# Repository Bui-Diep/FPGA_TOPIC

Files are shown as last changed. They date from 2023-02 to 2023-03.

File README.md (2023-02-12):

# FPGA_TOPIC
# Nghiên cứu xây dựng thiết bị kiểm tra bảng mạch chức năng của thiết thiết bị kiểm tra PKY-13 trên cơ sở FPGA.
## Research and build test equipment for functional circuit boards of PKY-13 test equipment on the basis of FPGA !!!
-----
## 3D and 2D images :
altium_3D
altium_2D
<br /><br /><br /><br /><br /><br />
<br /><br /><br />
<br /><br /><br /><br />

## Schematic : 
altium_sche

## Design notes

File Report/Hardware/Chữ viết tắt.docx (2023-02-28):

Chữ viết tắt:

Mạch giao tiếp | Khối truyền thông
- FPGA - USB - TTL - CMOS - AD - SDM - RAM - DC - JTAG - ROM - IC - VCC - GND - TXD - RXD - PCB - LED - OE - IC | - FPGA - UART - TX - RX - GND - TTL - COM - LSB - ASMD - FIFO - UCR - UCT - BRG - IC

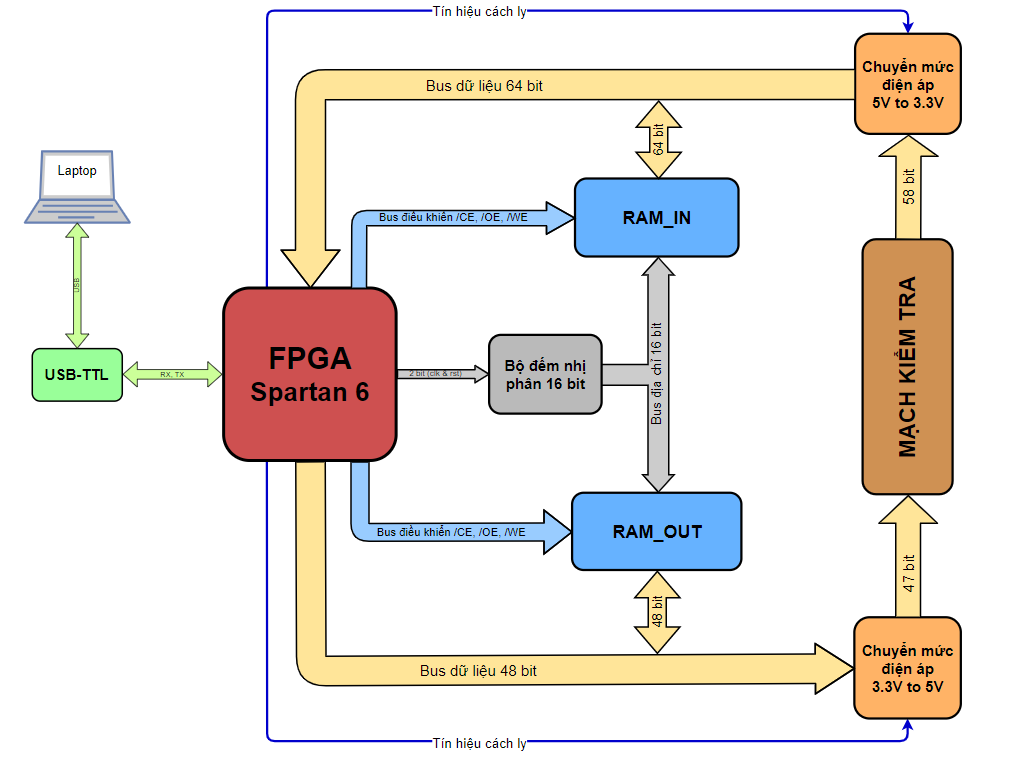
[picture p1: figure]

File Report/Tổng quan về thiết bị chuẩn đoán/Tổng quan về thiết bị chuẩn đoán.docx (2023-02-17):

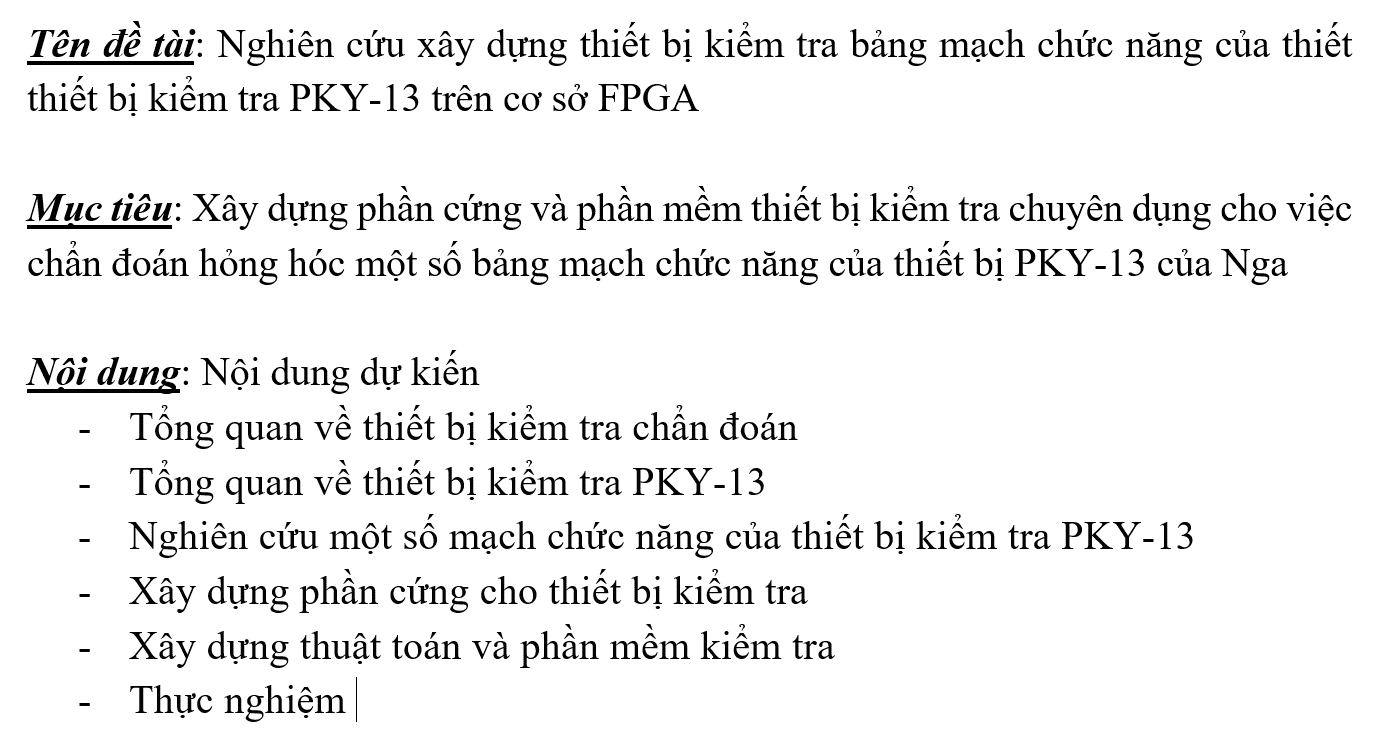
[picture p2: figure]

Báo cáo

Thiết bị kiểm tra chuẩn đoán là các thiết bị sử dụng để dự đoán tình hình hoạt động của thiết bị, khả năng cung cấp thông tin và đầu ra song song với các giá trị đúng. Chúng cũng có thể được sử dụng để kiểm tra chính xác của dữ liệu trong các ứng dụng.

Một số thiết bị kiểm tra chuẩn đoán thông dụng được sử dụng trong các ứng dụng khoa học cho phép các nhà nghiên cứu, kỹ thuật và các chuyên gia làm việc với các dữ liệu thực. Một số trong các thiết bị kiểm tra chuẩn đoán cho phép đầu ra song song để so sánh với các giá trị tham số, câu trả lời và hình ảnh.

Các thiết bị kiểm tra chuẩn đoán được sử dụng trong rất nhiều hãng sản xuất thiết bị, bao gồm cả các hãng lớn và nhỏ. Nhiều trong các thiết bị này được sử dụng trong các hệ thống quy trình và được thiết lập để theo dõi và giám sát các thông số của thiết bị.

Thiết bị kiểm tra chuẩn đoán hỏng hóc bảng mạch (PCB diagnostic tool) là dụng cụ phổ biến được sử dụng trong việc giám sát và kiểm soát các lỗi trên bảng mạch. Thiết bị này giúp bạn nhận ra và xác định các lỗi trên PCB (printed circuit board), từ những lỗi đơn giản như vi phạm hoặc gián đoạn vỡ dây đến những lỗi phức tạp hơn như hiện tượng ướt chân, áp suất và thất thoái pin. Thiết bị này không chỉ là hữu ích cho các nghiên cứu thực tế, nó còn giúp đảm bảo rằng PCB luôn làm việc chính xác và ổn định.

Thiết bị kiểm tra chuẩn đoán lỗi trên bảng mạch (debugging) là một công cụ khá hữu ích cho người lập trình. Nguyên tắc là phát hiện ra các lỗi ở bảng mạch, và sau đó xác định nguyên nhân gây ra lỗi để sửa lỗi. Điều tuyệt vời là bạn có thể sử dụng thiết bị kiểm tra chuẩn đoán lỗi trên bảng mạch để giúp bạn nhanh chóng tìm ra lỗi trong mã nguồn và sửa mã đúng chính xác.

Giới thiệu thiết bị kiểm tra PKY-13

Thiết bị kiểm tra PKY-13 là một loại thiết bị được phát triển bởi công ty Singer Instrumentation Laboratory. Nó được dùng để thực hiện đo lường tính hóa học trong nghiên cứu và kỹ thuật. Thiết bị có thể được sử dụng để đo lường ph một cách nhanh chóng và chính xác.

Nó được lựa chọn bởi tính chuyên nghiệp của nó, có thể tải đồ họa cung cấp bởi sinh ra và luận dịch các kết quả của phép thử vật lý. Thiết bị này được tích hợp với một trong những phần mềm quản lý dữ liệu phân tán dễ sử dụng nhất có sẵn.

PKY-13 là trang bị đầy đủ về đặc điểm thiết kế tốt nhất có thể. Cảnh báo âm thanh cảnh báo sự khét tiếng cường độ cao

Thiết bị kiểm tra PKY-13 là thiết bị đo mức độ nguy hiểm và cung cấp đọc số tuyệt đối, liều lượng KH và KOH tối thiểu. Nó hỗ trợ hai loại màn hình:

Màn hình 9 dòng tối ưu cho người sử dụng nhiều

Màn hình kích thước siêu lớn cho ít bộ nhớ và tính hiệu suất cao

Hãng sản xuất của thiết bị là Phycal Instruments, cung cấp phần cứng và phần mềm làm việc đều tốt. Không có triệu chứng bị gián đoạn hoặc hỏng hóc. Ngoài ra, thiết bị có một thiết kế chống bám bụi bằng thép không rỉ sét đáng tin cậy.

PKY-13 có một số tính năng chính, bao gồm:

Công nghệ Bluetooth 5.0: cung cấp một truyền sóng dài và ổn định với khoảng cách truyền sóng tối đa 10 mét.

Cảm biến IR: Cảm biến vào mặt tối ưu hóa việc kiểm tra và dò tìm các lỗi của thiết bị.

Công nghệ tiết kiệm pin cao: Lượng pin cho phép thiết bị sử dụng trong khoảng thời gian dài (tới gần 30 ngày).

Vân tay: Khả năng phát hiện vân tay của thiết bị được cải tiến để cung cấp độ bảo mật cao hơn.

Thiết kế cực nhỏ: Kích thước để bạn có thể mang đi để sử dụng mọi lúc và mọi nơi.

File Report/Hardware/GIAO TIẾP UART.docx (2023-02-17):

# PHẦN I. GIỚI THIỆU VỀ GIAO THỨC TRUYỀN THÔNG UART

Bộ truyền và nhận không đồng bộ UART để gửi dữ liệu qua một đường truyền nối tiếp

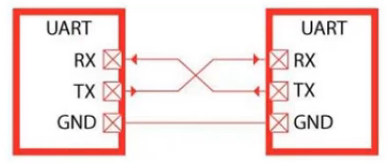
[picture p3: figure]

Hình 1: Giao thức truyền thông UART

Hai bên đều có TX và RX hai cặp đường này nối chéo với nhau và một đường đất nối chung nhau (GND). Chuẩn UART thường được sử dụng chung với chuẩn giao tiếp RS232, chuẩn giao tiếp xác định đặc tính điện, cơ, hàm và thủ tục để hai thiết bị có thể giao tiếp với nhau. Kết hợp này để truyền dữ liệu đi xa.

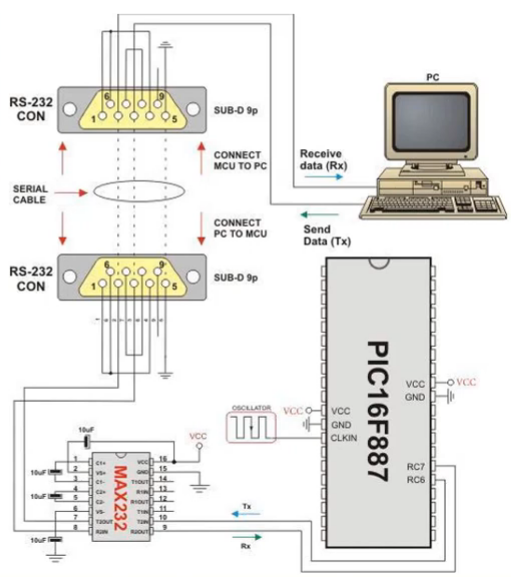
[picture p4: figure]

Hình 2: Kết hợp UART với RS232

UART sử dụng điện áp chuẩn TTL (mức cao ‘1’ ~ 5V; mức thấp ‘0’ ~ 0V).

Các máy tính ngày nay đã không còn sử dụng cổng COM RS232 vì chiếm nhiều không gian và hạn chế khả năng ứng dụng thay thế bằng cổng phổ biến hơn là cổng USB.

# 1. Khảo sát chi tiết khối UART

Bao gồm bộ phát (Transmitting) và bộ nhận (Receiving).

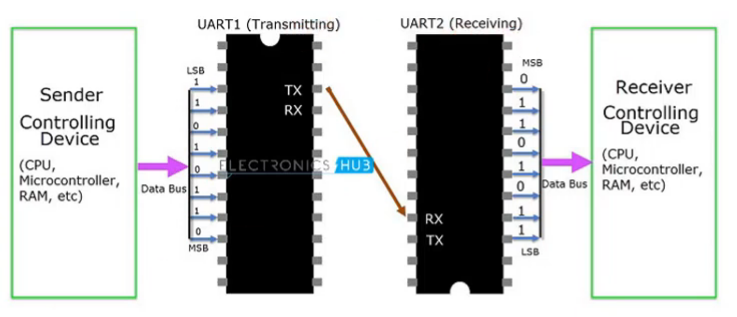
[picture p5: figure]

Hình 3: Mô tả cấu trúc UART

Bộ phát cần có một thanh ghi dịch đặc biệt để nạp dữ liệu song song và sau đó dịch từng bit ra với một tốc độ xác định ở chân (TX).

Bộ nhận cũng có một thanh ghi đặc biệt (vào nối tiếp - ra song song) đầu vào (RX) này được nối với đầu ra (TX) của bộ phát. Bộ nhận sẽ dịch từng bit dữ liệu vào và sau đó tổng hợp lại thành 1 gói dữ liệu giống như gói dữ liệu mà bộ phát truyền đến.

# 2. Khảo sát đường truyền dữ liệu của hệ thống phát và hệ thống nhận

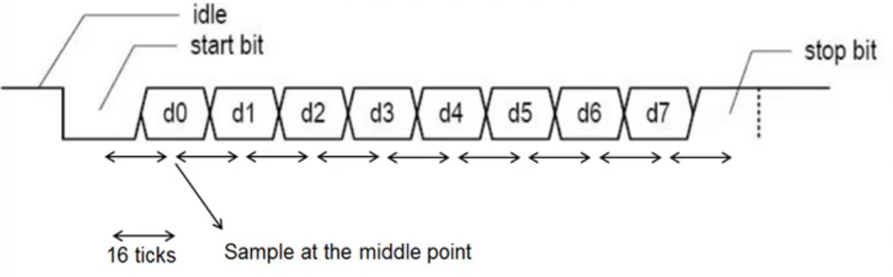
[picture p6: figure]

Hình 4: Khung truyền của giao thức UART

Ở trạng thái rỗi (iDLE) không thực hiện quá trình truyền nhận thì đường truyền ở mức logic ‘1’. Việc truyền dữ liệu bắt đầu bằng bit START(mức ‘0’). Tiếp theo đó, là những bit dữ liệu. Số lượng bit dữ liệu có thể là 6, 7 hoặc 8. Sau khi truyền xong các bit dữ liệu nếu có sử dụng kiểm tra parity thì tiếp theo là bit PARITY. Cuối cùng kết thúc bằng bit STOP (mức ‘1’). Số lượng bit Stop có thể là 1, 1.5 hoặc 2. Kết thúc quá trình truyền dữ liệu.

Bit PARITY là bit kiểm tra phát hiện lỗi trong quá trình truyền nhận. Đối với kiểm tra lẻ thì bit PARITY bằng ‘0’ khi tổng số bit ‘1’ trong gói dữ liệu là lẻ. Đối với parity chẵn thì bit PARITY bằng ‘0’ khi tổng số bit ‘1’ là chẵn.

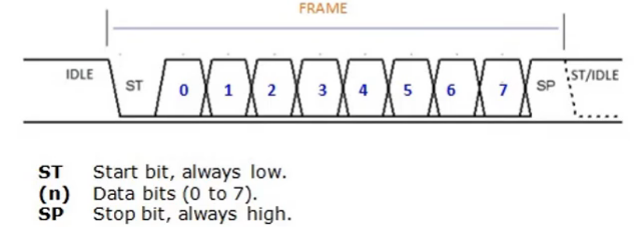
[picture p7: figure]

Hình 5: Trạng thái của quá trình nhận dữ liệu

Trong hệ thống, LSB của gói dữ liệu sẽ được truyền đầu tiên. Trong hình trình bày việc truyền dữ liệu 8bit dữ liệu, không có bit PARITY, 1bit STOP.

Trong hệ thống truyến dữ liệu UART do không có tín hiệu xung clock được truyền qua đường nối tiếp kết nối giữa hai hệ thống thì trước khi bắt đầu truyền, nhận bộ phát và bộ thu phải thiết lập thông số giống nhau: tốc độ baud, số bit dữ liệu, số bit stop và bit parity có sử dụng hay không. Thông thường, tốc độ baud là 2400, 4800, 9600, 19200, …

# PHẦN II. THIẾT KẾ BỘ NHẬN UART

Bộ nhận có sơ đồ khối 3 thành phần:

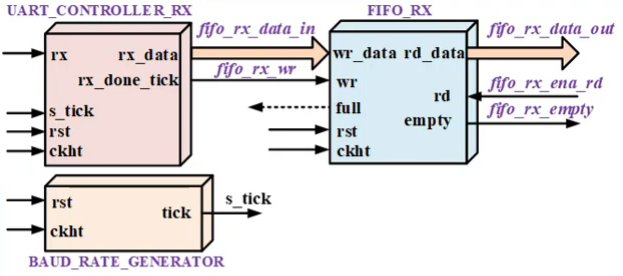
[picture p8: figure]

Hình 6: Sơ đồ khối nhận UART
- UART Controller Receiver (UCR): Mạch nhận dữ liệu từ chân RX thông qua lấy mẫu.
- Baud Rate Generator (BRG): Tạo ra xung lấy mẫu.
- Interface Circuit (IC): Mạch giao tiếp.

# 1. Thủ Tục Lấy Mẫu

Do không sử dụng xung clock khi truyền, bộ nhận sẽ nhận lại dữ liệu bằng cách sử dụng các tham số đã được xác định ban đầu. Bộ nhận sẽ dùng mạch lấy mẫu để tìm điểm giữa của những bit dữ liệu và sau đó tiến hành lưu giữ liệu.

Hầu hết các mạch lấy mẫu sẽ có tốc độ bằng 16 lần tốc độ baud, nghĩa là mỗi bit nối tiếp sẽ được lấy mẫu 16 lần.

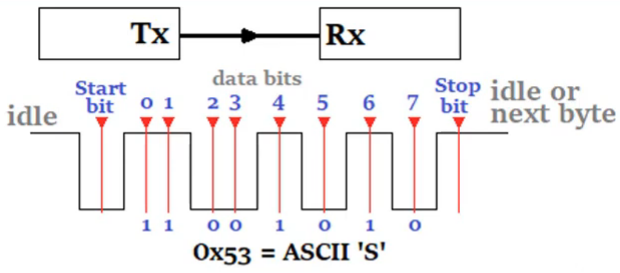
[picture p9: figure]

Hình 7: Vị trí lấy dữ liệu trên mỗi bit

Giả sử ta quy định truyền N bit dữ liệu và M bit stop, khi đó mạch lấy mẫu được thực hiện theo trình tự như sau:

- Bước 1: Bộ nhận đợi cho đến khi xuất hiện tín hiệu start chuyển xuống mức logic ‘0’, sau đó bộ nhận tiến hành khởi động bộ đếm lấy mẫu.
- Bước 2: Khi bộ đếm đạt giá trị bằng 7 tương ứng với 8 xung (đếm từ 0), thì tín hiệu vào đang ở điểm giữa của bit START. Lúc này bộ nhận xóa giá trị của bộ đếm lấy mẫu về 0 và bắt đầu khởi động lại để đếm bit dữ liệu đầu tiên D0.
- Bước 3: Khi bộ đếm đạt đến giá trị đếm là 15 tương ứng với 16 xung (đếm từ 0), khi đó tín hiệu vào đã đã đạt đến điểm giữa của bit giữ liệu đầu tiên D0. Bộ nhận tiến hành ghi nhận giá trị này vào thanh ghi để lưu trữ và khởi động lại bộ đếm tiến hành lưu trữ các dữ liệu tiếp theo.

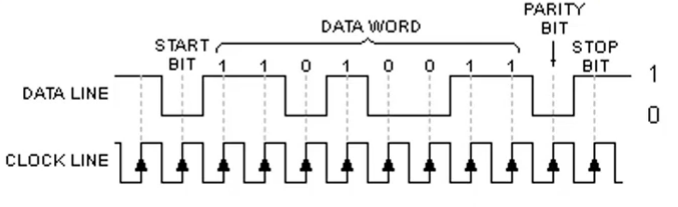
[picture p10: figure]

Hình 8: Sườn xung tại vị trí nhận giá trị
- Bước 4: Khối thu lặp lại bước 3 với N-1 lần đẻ nhận những bit dữ liệu còn lại.
- Bước 5: Nếu có bit PARITY được sử dụng thì lập lại bước 3 thêm một lần đẻ lấy giá trị bit PARITY.
- Bước 6: Lặp lại bước 3 M lần để lấy bit STOP từ khối phát. Hoàn thành nhận 1 khung dữ liệu.

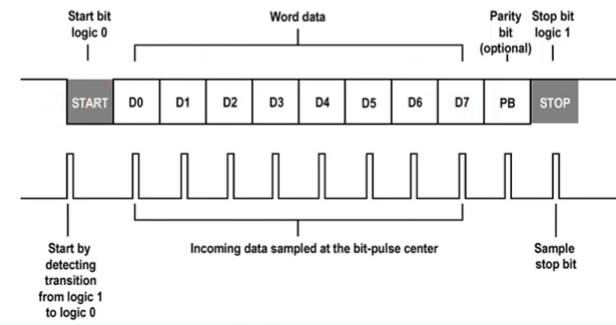
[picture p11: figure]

Hình 9: Xung tick tại vị trí nhận giá trị

Có thể xem như mạch lấy mẫu thực hiện chức năng của tín hiệu xung clock, thay vì sử dụng cạnh lên để xác định tín hiệu vào tồn tại, ta sử dụng xung lấy mẫu để ước lượng điểm giữa của mỗi bit.

# 3. Bộ Tạo Tốc Độ Baud

Mạch này sẽ phát ra tidn hiệu xung để lấu mẫu với tần số bằng 16 lần tần tốc độ baud đã chọn. Giả sử xung clock hệ thống là 50Mhz thì mạch tạo tốc độ baud chính là mạch đếm mod 163. Hay chính là mạch chia tần 50Mhz xuống 153600hz.

Hình 10: Khối tạo tốc độ baud

Tốc độ lấy mẫu bằng 19200*16 = 307200 xung/1s, còn gọi là xung tick đặt tên theo sơ đồ khối.

# 4. Bộ Nhận UART

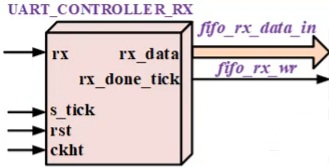
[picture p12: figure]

Hình 11: Điều khiển khối nhận UART

## 4.1. Xây dựng lưu đồ ASMD cho UCR

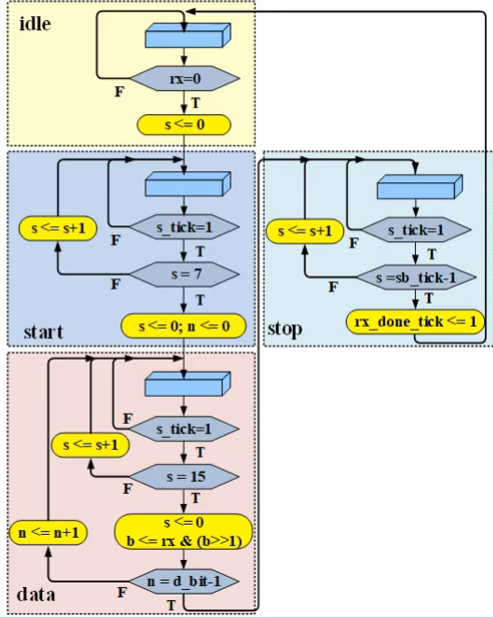
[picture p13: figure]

Hình 12: Lưu đồ thuật toán khối UCR

## 4.2. Code VHDL cho khối UCR

# 5. MẠCH GIAO TIẾP FIFO_RX

Trong hệ thống lớn, khối UART thường là một ngoại vi để phục vụ cho truyền dữ liệu nối tiếp. Hệ thống chính sẽ kiểm tra trạng thái của nó theo chu kỳ thời gian để nhận và xử lý tín hiệu được nhận. Mạch giao tiếp này có hai chức năng:

- Mạch tạo ra tín hiệu báo sẵn sàng cho việc nhận dữ liệu mới và ngăn chặn việc nhận dữ liệu lặp lại nhiều lần.
- Mạch tạo một bộ đệm cho hệ thống chính.

Bộ đệm FIFO là một vùng nhớ đệm dùng để lưu trữ dữ liệu nhận về từ khối UCR. Dung lượng bộ đếm có thể được thiết kế tùy ý để lưu trữ dữ liệu. Trong bộ đệm này thì dữ liệu được lưu vào trước thì sẽ được đọc ra trước.

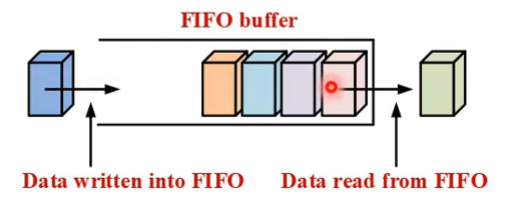
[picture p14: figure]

Hình 13: Mô hình bộ đệm FIFO

## 5.1. Các tín hiệu ghi dữ liệu vào bộ đệm FIFO

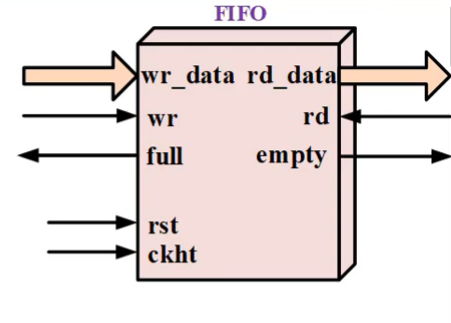
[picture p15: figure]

- wr_data : là ngõ vào nhận dữ liệu 8bit dùng để lưu vào FIFO. - wr : là tín hiệu điều khiển ghi dữ liệu vào FIFO. - full : là tín hiệu báo trạng thái bộ đệm FIFO đầy hay không đầy ( tích cực mức ‘1’). | Hình 14: Khối FIFO

## 5.2. Các tín hiêu đọc dữ liệu ra từ bộ đệm FIFO

- rd_data : là ngõ ra dữ liệu 8bit khi thực hiện đọc dữ liệu từ FIFO.
- rd : là tín hiệu điều khiển đọc dữ liệu từ FIFO.
- empty : là tín hiệu báo trạng thái bộ đệm FIFO rỗng hay không rỗng (tích cực mức ‘1’).

## 5.3. Hoạt động đọc/ghi dữ liệu FIFO có 8 ô nhớ

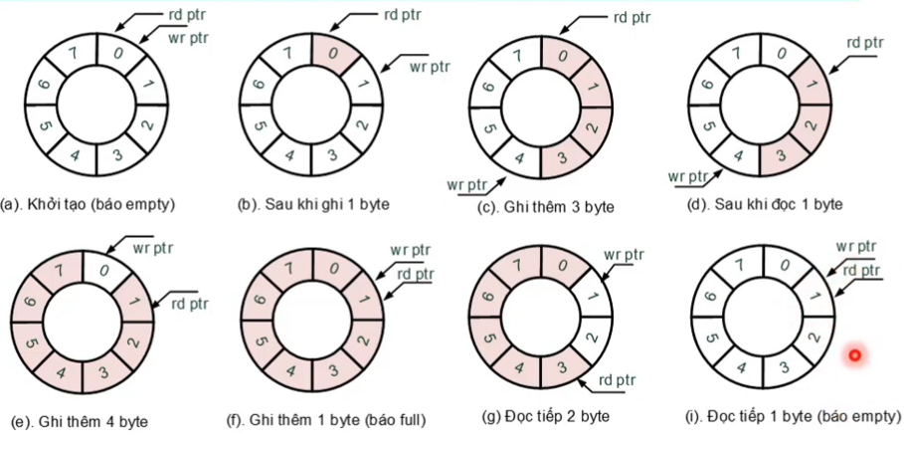
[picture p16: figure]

Hình 15: Các trạng thái của khối FIFO
- rd_ptr : là con trỏ đọc dữ liệu.
- wr_ptr : là con trỏ ghi dữ liệu.

## 5.4. Ứng dụng của FIFO trong hệ thống UART

Hình 16: Ứng dụng của FIFO trong hệ thống UART
- UCR giao tiếp với FIFO để ghi dữ liệu:
- Tín hiệu “rx_data” nối đến ngõ vào “wr_data” của FIFO để ghi dữ liệu sau nhận được vào FIFO.
- Tín hiệu “rx_done_tick” nối đến ngõ “wr” của FIFO để điều khiển FIFO ghi dữ liệu.
- Tín hiệu “full” không sử dụng trong ứng dụng này.
- Hệ thống chính (HTC) giao tiếp với FIFO để đọc dữ liệu:
- Tín hiệu “rx_data” của FIFO nối đến ngõ vào của HTC để nhận dữ liệu.
- Tín hiệu “rd” của FIFO nối đến tín hiệu điều khiển đọc của HTC.
- Tín hiệu “empty” của FIFO sẽ nối đến HTC để báo trạng thái.

## 5.5. Sơ đồ khối

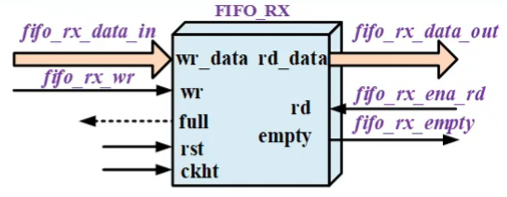
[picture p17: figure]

Hình 17: Khối FIFO_RX

## 5.6. Code VHDL cho bộ đệm FIFO_RX

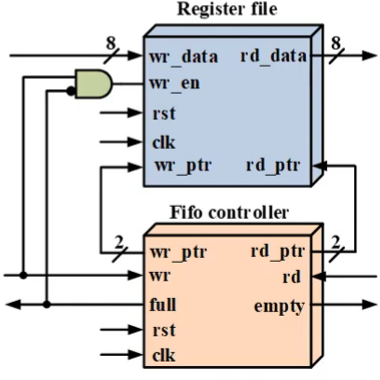
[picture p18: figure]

Hình 18: Modul của khối FIFO_RX

# PHẦN III. THIẾT KẾ BỘ PHÁT UART

Cấu trúc bộ phát UART gồm 3 phần:

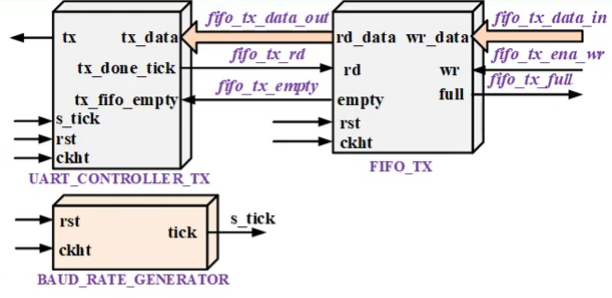
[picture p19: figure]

Hình 19: Sơ đồ khối phát UART
- UART Controller Transmitter (UCT): Mạch phát dữ liệu lên đường truyền nối tiếp.
- Baud Rate Generator (BRG): Tạo ra xung lấy mẫu.
- Interface Circuit (IC): Mạch giao tiếp.

Mạch phát dữ liệu cũng tương tự bộ phát dữ liệu nhưng ngược lại. hệ thống chính ghi vào bộ đệm FIFO và bộ phát UART sẽ đọc dữ liệu từ bộ đệm FIFO để phát dữ liệu đi.

Bộ phát UART có thanh ghi dịch dữ liệu từng bit ở chân “tx” ở một tốc độ cố định. Tốc độ này được điều khiển bởi tín hiệu tick của khối BRG. Thường thì khối nhận và khối phát trong UART sẽ dùng chung khối BRG.

Các tín hiệu vào ra:

Hình 20: Sơ đồ khối phát UART
- Tín hiệu vào “tx_data” 8 bit nhận dữ liệu từ khối FIFO để truyền đi.
- Tín hiệu ra “tx_done_tick” dùng để báo hiệu khi truyền xong một byte dữ liệu.
- Tín hiệu vào “tx_fifo_empty” dùng để kiểm tra FIFO rỗng hay không.
- Tín hiệu vào “s_tick” dùng để nhận xung lấy mẫu từ khồi BRG.
- Tín hiệu ra “tx” dùng để xuất dữ liệu nối tiếp từng bit.
- Các tín hiệu còn lại là “clkht” và “rst”.

# 1. Khối phát UART

## 5.7. Xây dựng lưu đồ ASMD cho UCT

Thực hiện các trạng thái ILDE, START, DATA, STOP để tiến hành truyền nối tiếp từng bit. Một bit sẽ được dịch ra mỗi lần sau khi có 16 xung tick. Khi truyền hoàn thành thì khối UCT sẽ tạo ra 1 xung cho tín hiệu tx_done_tick.

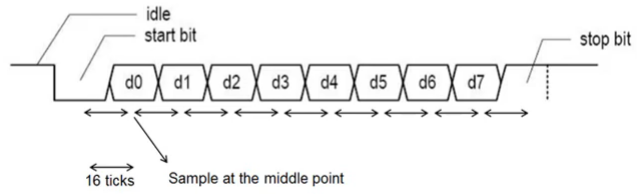
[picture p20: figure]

Hình 21: Khung dữ liệu của bộ phát UART

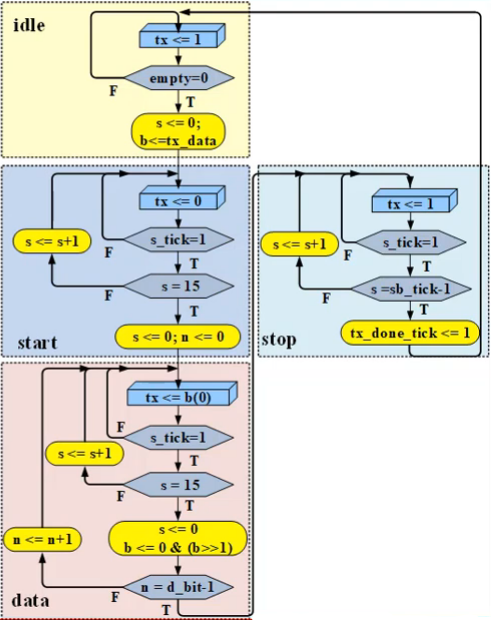
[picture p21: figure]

Hình 22: Lưu đồ thuật toán khối UCT

## 5.8. Code VHDL cho khối UCT

# 6. Khối FIFO_TX

## 6.1. Sơ đồ khối

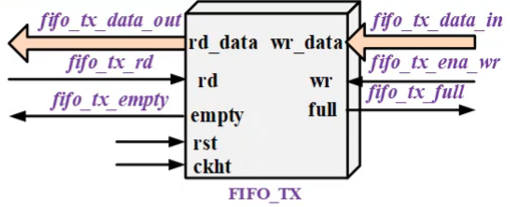
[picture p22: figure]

Hình 23: Khối FIFO_TX

## 6.2. Code VHDL cho bộ đệm FIFO_TX

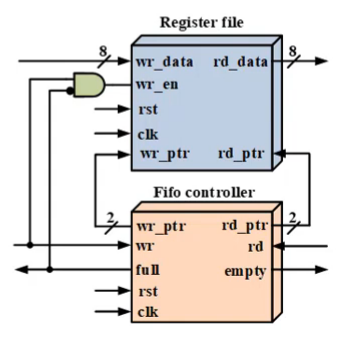
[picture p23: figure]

Hình 24: Modul của khối FIFO_TX

# PHẦN IV. THIẾT KẾ HỆ THỐNG UART HOÀN CHỈNH

# 1. Sơ đồ khối

Bằng cách kết hợp bộ phát và bộ nhận sẽ tạo thành hệ thống UART hoàn chỉnh.

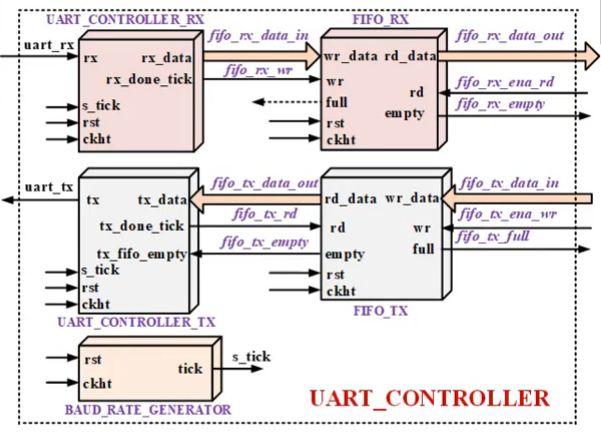
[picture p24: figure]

Hình 25: Sơ đồ khối hệ thống UART hoàn chỉnh

Tín hiệu xung clkht và rst cung cấp cho tất cả các khối.

Khối tạo tốc độ baud cung cấp tín hiệu s_tick cho khối UART_CONTROLLER_RX (UCR) và khối UART_CONTROLLER_TX (UCT).

# 7. Các tín hiệu vào ra


Hình 26: Khối UART hoàn chỉnh
- Nhận dữ liệu:
- uart_rx : ngõ vào nhận dữ liệu nối tiếp để đưa tới FIFO_RX
- fifo_rx_data_out : ngõ ra 8 bit đọc dữ liệu từ FIFO_RX để đưa tới hệ thống chính.
- fifo_rx_ena_rd : ngõ vào nhận tín hiệu điều khiển yêu cầu đọc dữ liệu từ FIFO_RX.
- fifo_rx_empty : ngõ ra báo trạng thái empty của FIFO_RX.
- Truyền dữ liệu:
- uart_tx : ngõ ra phát dữ liệu nối tiếp.
- fifo_tx_data_in : ngõ vào 8 bit nhận dữ liệu từ hệ thống chính để đưa tới FIFO_TX.
- fifo_tx_ena_wr : ngõ vào nhận tín hiệu điều khiển yêu cầu ghi dữ liệu từ FIFO_TX.
- fifo_tx_full : ngõ ra báo trạng thái full của FIFO_TX.

Giao tiếp FPGA với máy tính qua giao thức UART | 2

EWEWEWEWThiết kế mạch giao tiếp sử dụng AD | 2

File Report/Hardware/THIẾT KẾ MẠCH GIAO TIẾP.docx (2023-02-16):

# THIẾT KẾ MẠCH GIAO TIẾP

Mục tiêu: Xây dựng lên bảng mạch thực hiện nhiệm vụ kết nối KIT FPGA với mạch khảo sát (đồng bộ mức tín hiệu điệp áp giữa các bộ phận trong phần cứng).

Sử dụng:

- Phần cứng: (các thành phần chính)
  - Modul FPGA XCSL25-2FTG256 : Bộ xử lý tín hiệu trung tâm.
  - IC TXS0108E : Chuyển đổi mức điện áp 3.3V-5V.
  - IC CH340C : Truyền thông nối tiếp USB-TTL.
  - IC AS7C1026B-12TCN: SRAM 64kByte.
  - IC LM1117-xV : Ổn áp 5V, 3.3V, 2.5V, 1.8V, 1.2V.
  - IC CD4040B : Bộ đếm nhị phân 12bit.
- Phần mềm:
- Altium Designer.

# 1. Giới thiệu về Module FPGA XC6SLX25-2FTG256


a) | b)

Hình 1: Module mạch FPGA XC6SLX25-2FTG256 a)mặt trước; b)mặt sau

Module FPGA là một mạch in 8 lớp với chíp FPGA Spartan 6 XC6SLX25-2FTG256, Flash ROM XCF08S, SMD, khối tạo dao động 50 MHz SMD. Về giao diện module này có giao tiếp JTAG 6x1 để nạp cấu hình cho FPGA và 02 chân dùng jumper 2.54mm 40x2 chân để cắm trực tiếp xuống module ngoại vi Motherboard, khoảng cách 2 jumper là 68.58mm (2700mil).

Đây là dòng chip giá thành thấp (low-cost) của Xilinx, tài nguyên cơ bản gồm 24061 phần tử logic khả trình (logic cells), 38 khối xử lý tín hiệu số (DSP slices) và 52x18Kb khối nhớ tập trung (Block RAM). Chip sử dụng trong mạch có kiểu đóng gói 256 FTG, gồm 256 chân, trong đó 184 chân có thể lập trình được. XC6SLX25 được cấp các nguồn cơ bản DC 3.3V, DC 2.5V, DC1.8V và DC 1.2V với yêu cầu dòng tổng cho 3.3V không vượt quá 2A. FPGA được lập trình thông qua giao tiếp JTAG.

Xilinx platform Flash XCF08P VO48 là IC chứa ROM cấu hình cố định cho FPGA, dung lượng 8Mb sử dụng giao diện JTAG và điện áp cấp 3.3V. Khối tạo dao động sử dụng chíp oscilliator SMD 4 pin cấp nguồn clock cố định 50MHz nối vào chân A9 của FPGA.

# 2. Thiết kế mạch sử dụng phần mền Altium Designer

## 2.1. Khối nguồn

Chức năng chính của LM1117 là điều chỉnh điện áp đầu ra của nguồn điện bằng cách duy trì mức điện áp không đổi mặc dù điện áp đầu vào dao động hoặc dòng điện tải thay đổi. Nó thực hiện điều này bằng cách sử dụng tham chiếu điện áp và bộ khuếch đại lỗi để so sánh điện áp đầu ra với tham chiếu và điều chỉnh đầu ra khi cần để duy trì mức điện áp mong muốn. LM1117 thường được sử dụng để cung cấp điện áp ổn định cho các bộ vi điều khiển, cảm biến và các linh kiện điện tử khác yêu cầu điện áp không đổi để hoạt động bình thường. Nó cũng có thể được sử dụng trong các hệ thống chạy bằng pin để đảm bảo cung cấp điện áp ổn định cho tải khi điện áp pin giảm.

### Datasheet LM1117

Khối nguồn được thiết kế tập trung trên Motherboard, nguồn vào là DC5V, 4A. Khối nguồn bao gồm 5 IC nguồn (Voltage regulator):

- 1x LM1117 5V 1A (cấp nguồn nuôi cho mạch bảng mạch kiểm tra và nuôi các IC cần nguồn 5V).
- 1x LM1117 3.3.V 1A (cấp nguồn nuôi 3.3V cho mạch FPGA và nuôi các IC cần nguồn 3.3V)
- 1xLM1117 2.5V 1A, 1xLM1117 1.8V 1A, 1xLM1117 1.2V 1A (cấp nguồn nuôi 2.5V, 1.8V và 1.2V cho mạch FPGA).

Từ điều kiện hoạt động được đề xuất có trong Datasheet của các IC, ta có được sơ đồ bên dưới về đồng bộ điện áp giữa các IC.


Hình 2: Sơ đồ phân chia điện áp trong thiết kế mạch


Hình 3: IC ổn áp 3.3V và jack nguồn DC 5V

Để lọc nhiễu tần số cao sử dụng dải tụ gốm 104 song song nối tới GND.


Hình 4: Tụ khử nhiễu cho nguồn 3.3V

## 2.2. Khối truyền thông USB-TTL

IC CH340C là một chip sử dụng để làm giao tiếp USB-to-serial trên các thiết bị khác nhau. Nó được sử dụng trong nhiều loại thiết bị khác nhau, như các module USB-to-serial, các module cảm biến, các module truyền thông không dây, và các board mạch điều khiển.

IC CH340C có thể hỗ trợ các tốc độ truyền dữ liệu từ 300 baud đến 3 megabaud, và có thể làm việc với các định dạng dữ liệu như data bits 5, 6, 7, hoặc 8; stop bits 1 hoặc 2; và parity none, even, odd, mark, hoặc space. Nó cũng có thể được sử dụng để hỗ trợ các giao thức khác nhau, như giao thức chuẩn RS232, RS485, và TTL.

Tổng quan, chức năng của IC CH340C là giúp cho các thiết bị khác nhau có thể giao tiếp với máy tính hoặc các thiết bị khác thông qua giao diện USB bằng cách chuyển đổi dữ liệu giữa các giao thức USB và các giao thức truyền dữ liệu khác.

### DataSheet CH340


Hình 5: Schematic IC CH340C

Truyền dữ liệu nối tiếp giữa PC và FPGA.

## 2.3. Khối chuyển chế độ


Hình 6: Schematic khối chuyển chế độ

Sử dụng 1 công tắc 3 vị trí (kép) và 3xLED 3mm. Hình 5, SW1B làm nhiệm vụ chuyển mạch kết nối tới VCCB (chân xác định mức điện áp ra của IC TXS0108E). Chuyển đổi giữa 5V, 3.3V, GND cho phép đầu ra của mạch giao tiếp tương ứng với điện áp của chân VCCB. Khi gạt công tắc chuyển mạch thì LED chỉ thị cũng sáng theo điện áp được chọn.

## 2.4. Khối chuyển mức điện áp 3.3V-5V

IC TXS0108E là một chuyển đổi điện áp 8-kênh có thể chuyển đổi từ một điện áp đầu vào cao hơn về một điện áp đầu ra thấp hơn. Nó được sử dụng để chuyển đổi điện áp từ một nguồn có điện áp cao về một nguồn có điện áp thấp hơn, ví dụ như chuyển đổi điện áp từ một pin tới một vi điều khiển. TXS0108E cũng có thể được sử dụng để chuyển đổi từ một nguồn điện áp tĩnh về một nguồn điện áp tĩnh khác với điện áp khác nhau. Nó có thể làm việc với các điện áp đầu vào từ 1.2 V đến 5.5 V và có thể chuyển đổi điện áp đến mức độ chính xác cao. Nó cũng có khả năng tự bảo vệ khi có quá tải hoặc quá nhiệt.

Sử dụng 7x IC TXS0108E, trong đó 6 IC(dùng 74 kênh) làm bộ phận chuyển đổi điện áp từ RAM(3.3V) tới Mạch kiểm tra(5V). 1 IC chuyển đổi điện áp đường CLK và RST tới bộ đếm nhị phân (dùng 2 kênh cho bộ đếm địa chỉ RAM_IN, 2 kênh cho bộ đếm địa chỉ RAM_OUT )

### DataSheet TXS0108E


Hình 7: Schematic IC TXS0108E
- IC này mắc chung :
  - Chân định mức điện áp đầu vào (VCCA) mức 3.3V.
  - Chân cho phép IC hoạt động (OE) mức 3,3V.
  - GND.
  - Chân định mức điện áp đầu ra (VCCB) (theo khối chuyển chế độ).
- Các chân truyền tín hiệu (A, B) được độc lập nhau để chuyển 3.3V-5V.
  - Các chân A kết nối trực tiếp tới bus dữ liệu của RAM.
  - Các chân B kết nối trực tiếp tới СНП-135 (Giao tiếp với mạch kiểm tra).

## 2.5. Khối chân giao tiếp

- Sử dụng 2 x header 40x2 (kết nối với Module FPGA), khoảng cách giữa 2 header là 68.58mm (2700mil).


Hình 8: Header kết nối với FPGA
- Sử dụng СНП-135 (kết nối tới mạch kiểm tra).


Hình 9: Header kết nối với Mạch kiểm tra

## 2.6. Khối RAM

IC AS7C1026B-12TCN là một loại RAM CMOS (Complementary Metal-Oxide-Semiconductor) có cấu trúc nhôm và hỗ trợ kết nối asynchronous, có nghĩa là nó có khả năng điều chỉnh tốc độ đồng bộ hóa dữ liệu theo nhu cầu của hệ thống. Nó có dung lượng 64KB và có khả năng lưu trữ tối đa 16bit dữ liệu. RAM là bộ nhớ truy cập ngẫu nhiên, có nghĩa là nó cho phép hệ thống điện tử truy cập và đọc dữ liệu từ bộ nhớ một cách linh hoạt và nhanh chóng. RAM là bộ nhớ tạm thời, có nghĩa là nó chỉ lưu trữ dữ liệu trong khi hệ thống điện tử đang hoạt động và dữ liệu sẽ bị mất khi hệ thống được tắt.

### Datasheet AS7C1026B


Hình 10: SRAM_IN | Hình 11: SRAM_OUT

Khối RAM_IN để lưu trữ dữ liệu truyền từ FPGA tới mạch kiểm tra. Vì là kiểu truyền song song, cần 47bit dữ liệu được truyền cùng một lúc tới mạch kiểm tra nên ta chọn ghép nối RAM theo kiếu song song(chung bus địa chỉ, ghép nối bus dữ liệu, chung bus điều khiển). kết quả ghép nối 3IC RAM ta được một khối RAM_IN có dung lượng 192kByte với 16bit địa chỉ(A0…A15), 48bit dữ liệu(D0…D47), 3bit điều khiển(/OE, /WE, /CE ). Khối RAM_IN dư 1bit dữ liệu(D47) không dùng tới nên ta sử dụng trở 10k kéo xuống GND.

Khối RAM_OUT để lưu trữ dữ liệu truyền từ mạch kiểm tra tới FPGA. Vì là kiểu truyền song song, cần 58bit dữ liệu được truyền cùng một lúc tới PFGA nên ta chọn ghép nối RAM theo kiếu song song(chung bus địa chỉ, ghép nối bus dữ liệu, chung bus điều khiển). kết quả ghép nối 4IC RAM ta được một khối RAM_OUT có dung lượng 256kByte 16bit địa chỉ(A0…A15), 64bit dữ liệu(D0…D47), 3bit điều khiển(/OE, /WE, /CE ).Khối RAM_OUT dư 6bit dữ liệu(D58…D63) không dùng tới nên ta sử dụng trở 10k kéo xuống GND.

## 2.7. Khối bộ đếm nhị phân 12 bit

CD4040B là một ic đếm số nhị phân 12bit dùng để phân chia tần số. Nó có một đầu vào nhị phân (clock) và một đầu ra nhị phân cho mỗi trạm đếm. Khi tần số đầu vào tăng, mỗi lần xung đầu vào sẽ khiến các đầu ra liên tiếp được bật theo thứ tự từ 0 đến 4095. CD4040B có thể được sử dụng trong nhiều ứng dụng khác nhau, như đồng hồ số, bộ phân tần số, và máy tạo dạng sóng. Nó có một tốc độ hoạt động tối đa là 10 MHz và có một đầu vào clear, khi được giữ thấp sẽ khởi tạo lại đếm về 0.

### Datasheet CD4040B


Hình 12: Bộ đếm cho khối RAM_IN | Hình 13: Bộ đếm cho khối RAM_OUT

Hai khối đếm nhị phân dùng để đếm địa chỉ cho hai khối RAM_IN và khối RAM_OUT. Nối 12 bit đếm của mỗi bộ đếm vào chân địa chỉ của 2 khối RAM tương ứng. Vì kênh địa chỉ của khối RAM có 16bit mà bộ đếm chỉ có 12bit nên các bit địa từ A12…A15 của khối RAM ra sẽ gán mức logic ‘0’ (dùng trở 10k kéo xuống GND).

Recommended operating conditions

Tham số | Sym | Min(V) | Nominal(V) | Max(V) | VCC(V) | Device IC
Input voltage | VIH | 2.2 | - | VCC+0.5 | 5.0 | AS7C1026B
| VIL | -0.5 | - | 0.8
Output voltage | VOL | - | - | 0.4
| VOH | 2.4 | - | -
Input voltage | VIH | 3.5 | 3 | - | 5.0 | CD4040B
| VIL | - | 2 | 1.5
Output voltage | VOL | - | 0 | 0.05
| VOH | 4.95 | 5 | -
Input voltage | VIH | | | | 3.3 - 5 | TXS0108E
| VIL
Output voltage | VOL
| VOH
Input voltage | VIH | | | | 3.3 | CH340C
| VIL
Output voltage | VOL
| VOH
Input voltage | VIH | | | | 3.3- 2.5- 1.8- 1.2 | FPGA
| VIL
Output voltage | VOL
| VOH

Điều kiện để hai IC có thể giao tiếp được với nhau: VOL<VIL; VOH>VIH.

Thiết kế mạch giao tiếp sử dụng AD | 2

EWEWEWEWThiết kế mạch giao tiếp sử dụng AD | 2

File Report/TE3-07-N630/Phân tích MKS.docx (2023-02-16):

# IC Sử Dụng Trong Mạch Khảo Sát

NO. | IC NAME | AMOUNT | FUNCTION | LINK
1 | 133TM5 # | 10 | Vi mạch đại diện cho 4 D-triggers (D-Triger) | https://russian-electronics.com/products/ics-unf-modules-microassemblies/:133tm5
2 | 134PM1 # | 6 | Vi mạch 134PM1 là 4 phần tử lưu trữ (D-Triger) | https://zapadpribor.com/134rm1/
3 | 133ЛA3 * | 7 | Microassemblies 133LА3 là 4 phần tử logic 2I-NЕ. | https://russian-electronics.com/products/ics-unf-modules-microassemblies/:133la3
4 | 136ЛА3 * | 5 | Chip 136LA3 là 4 phần tử logic 2I-NOT. | https://eandc.ru/catalog/detail.php?ID=245
5 | 106ЛА8A * | 19 | Vi mạch 106LA8 là bốn phần tử logic 2I-NOT với đầu ra bộ góp hở | https://eandc.ru/catalog/detail.php?ID=18821
6 | 133ЛA8 * | 1 | Vi mạch 133LA8 là bốn mạch hai đầu vào AND-NOT với đầu ra cực góp hở | https://russian-electronics.com/products/ics-unf-modules-microassemblies/:133la8
7 | 136ЛН1 | 15 | Mạch tích hợp cấu trúc cổng logic 6 NOT. | https://russian-electronics.com/products/ics-unf-modules-microassemblies/:136ln1
8 | 136ЛР3 | 8 | Chip 136LR3 là phần tử logic 2-2-2-3I-4OR-NOT với khả năng mở rộng bằng OR. | https://eandc.ru/catalog/detail.php?ID=249
9 | 133ЛA4 | 1 | Vi mạch đại diện cho ba phần tử logic 3AND-NOT. | https://russian-electronics.com/products/ics-unf-modules-microassemblies/:133la4
10 | 133ЛA1 | 1 | Vi mạch đại diện cho hai phần tử logic 4AND-NOT, một trong số chúng có thể mở rộng bằng phần tử OR. | https://russian-electronics.com/products/ics-unf-modules-microassemblies/:133la1
11 | 134КП10 | 20 | Vi mạch 134KP10 ghép 8 kênh trong ra 1 | https://eandc.ru/catalog/detail.php?ID=220
12 | 136ЛР1 | 12 | Chip 136LR1 là 2 phần tử logic 2-2I-2OR-NOT, một phần tử có thể mở rộng bằng OR. | https://eandc.ru/catalog/detail.php?ID=248
13 | B18 | 22 | Tụ thanh
14 | K56J | 6 | Trở thanh


15 | СНП-135 135 PIN (45*3)
16 | X160P-A | 160 PIN (80*2)

*, # : Linh kiện có cùng chức năng.

# CHÂN GIAO TIẾP

- СНП-135 : Cấu tạo 3 hàng chân (X2A, X2B, X2C); mỗi hàng chứa 45 PIN; tổng 135 PIN.

ROW | IN | OUT | I/O | VCC | GND | NC
X2A | | | 43 | 0 | 0 | 2
X2B | | | 27 | 6 | 6 | 6
X2C | | | 35 | 0 | 0 | 10
TOTAL | | | 105 | 6 | 6 | 18

## Tổng số chân GPIO của FPGA cần dùng (không bao gồm VCC và GND)

NO. | PIN USE | COMMUNICATE | LEVEL | NOTE
| 105 | СНП-135 | 5V | Bảng mạch khảo sát
| 4 | W25Q32 | 3.3V | ROM 32kbit (4kbyte)
| 2 | CH340C | 3.3V | USB - TTL
TOTAL | 111 PIN (FPGA) cho thiết kế mạch giao tiếp

## Bảng kết nối của СНП-135.

PIN NO. | PIN NAME | NET LABLE | ROW | I/O | NOTE
| | e4-14 | X2A | | O(F8, E7); X1A(43); I(E4, F5)
| | d1-14 | X2A | | O(F8, E7); X1B(133); I(D1, F3)
| | e7-8 | X2A | | O(E7, F8); X1B(119); I(F4, H4)
| | e7-14 | X2A | | O(E7, F8); X1B(132); I(F2, K3)
| | b3-14 | X2A | | X1B(134); I(B3, E3)
| | b2-14 | X2A | | X1B(147); I(B2, E2)
| | e4-3 | X2A | | O(H8); X1A(50); I(E4, F5)
| | d1-3 | X2A | | O(H8); X1B(126); I(D1, F3)
| | f4-3 | X2A | | O(H8); X1B(111); I(F4, H4)
| | f2-3 | X2A | | O(H8); X1B(129); I(F2, K3)
| | b3-3 | X2A | | X1B(125); I(B3, E3)
| | b2-3 | X2A | | X1B(143); I(B2, E2)
| | e4-13 | X2A | | O(H7); X1A(65); I(E4, F5)
| | d1-13 | X2A | | O(H7); X1B(128);I (D1, F3)
| | f4-13 | X2A | | O(H7); X1B(115); I(F4, H4)
| | f2-13 | X2A | | O(H7); X1B(130); I(F2, K3)
| | b3-13 | X2A | | X1B(131); I(B3, E3)
| | b2-13 | X2A | | X1B(146); I(B2, E2)
| | e4-2 | X2A | | O(K5); X1B(93); I(E4, F5)
| | d1-2 | X2A | | O(K5); X1B(89); I(D1, F3)
| | f4-2 | X2A | | O(K5); X1B(88); I(F4, H4)
| | f2-2 | X2A | | O(K5); X1B(99); I(F2, K3)
| | b3-2 | X2A | | X1B(127); I(B3, E3)
| | b2-2 | X2A | | X1B(145); I(B2, E2)
| | e4-1 | X2A | | O(K4); X1B(112); I(E4, F5)
| | d1-1 | X2A | | O(K4); X1B(109); I(D1, F3)
| | f4-1 | X2A | | O(K4); X1(B106); I(F4, H4)
| | f2-1 | X2A | | O(K4); X1B(117); I(F2, K3)
| | b3-1 | X2A | | X1(B135); I(B3, E3)
| | b2-1 | X2A | | X1B(149); I(B2, E2)
| | e8-1 | X2A | | X1A(48); I(E8)
| | e8-12 | X2A | | X1A(40); I(E8)
| | b6-3 | X2A | | I(B6)
| | f9-8 | X2A | | I(H10, K7, K9, F9)
| | f9-9 | X2A | | I(F9, H10, K7, K9)
| | f9-10 | X2A | | I(F9, H10, K7, K9)
| | a37 | X2A | | X1B(91)
| | a38 | X2A | | X1B(94)
| | a39 | X2A | | X1B(98)
| | a40 | X2A | | X1(B101)
| | a41 | X2A | | X1B(104)
| | a42 | X2A | | X1B(121)
| | a43 | X2A | | X1B(122)
| | | X2A | NC
| | | X2A | NC
| | | X2B | GND
| | d5-14 | X2B | | X1B(86); I(D5, E5)
| | b3 | X2B | | X1A(16)
| | | X2B | VCC
| | d2-14 | X2B | | X1B(120); I(D4, D2)
| | b6 | X2B | | X1A(23)
| | d5-3 | X2B | | X1B(82); I(D5, E5)
| | b8 | X2B | | X1A(31)
| | d2-3 | X2B | | X1B(114); I(D2, D4)
| | | X2B | VCC
| | b11 | X2B | | X1A(53)
| | b12 | X2B | | X1A(54)
| | | X2B | GND
| | d5-13 | X2B | | X1B(84); I(D5, E5)
| | b6-1 | X2B | | O(B6)
| | d2-13 | X2B | | X1B(116); I(D2, D4)
| | b6-4 | X2B | | O(B6)
| | | X2B | VCC
| | d5-2 | X2B | | X1B(83); I(D5, E5)
| | b6-10 | X2B | | O(B6)
| | | X2B | GND
| | d2-2 | X2B | | X1B(144); I(D2, D4)
| | b6-13 | X2B | | O(B6)
| | | X2B | NC
| | | X2B | GND
| | d5-1 | X2B | | X1B(85); I(D5, E5)
| | d2-1 | X2B | | X1B(148); I(D2, D4)
| | | X2B | VCC
| | | X2B | NC
| | | X2B | NC
| | b31 | X2B | | X1A(80)
| | e8-9 | X2B | | X1A(34); I(E8)
| | | X2B | GND
| | e8-4 | X2B | | X1A(38); I(E8)
| | | X2B | NC
| | | X2B | VCC
| | a4-3 | X2B | | O(A4); I(A4)
| | b38 | X2B | | X1B(95)
| | b39 | X2B | | X1B(100)
| | | X2B | NC
| | | X2B | NC
| | | X2B | VCC
| | f7-5 | X2B | | O(F7); X1A(71)
| | f7-3 | X2B | | O(F7); X1A(56)
| | | X2B | GND
| | e7-1 | X2C | | X1A(75); I(E7)
| | e7-6 | X2C | | X1A(59); I(E7)
| | e7-9 | X2C | | X1A(62); I(E7)
| | e7-12 | X2C | | X1A(64); I(E7)
| | c5 | X2C | | X1A(22)
| | c6 | X2C | | X1A(28)
| | c7 | X2C | | X1A(29)
| | c8 | X2C | | X1A(30)
| | b2-8 | X2C | | I(D1, D2, D5, B2, B3, E4, F2, F4)
| | b2-9 | X2C | | I(D1, D2, D5, B2, B3, E4, F2, F4)
| | b2-10 | X2C | | I(D1, D2, D5, B2, B3, E4, F2, F4)
| | d4-8 | X2C | | I(D4, E2, E3, E5, F3, F5, H4, K3)
| | d4-9 | X2C | | I(D4, E2, E3, E5, F3, F5, H4, K3)
| | d4-10 | X2C | | I(D4, E2, E3, E5, F3, F5, H4, K3)
| | | X2C | NC
| | b4-8 | X2C | | O(B4)
| | a10-1 | X2C | | I(A10)
| | a10-4 | X2C | | I(A10)
| | b10-13 | X2C | | I(B10)
| | | X2C | NC
| | a4-4 | X2C | | I(A4)
| | a4-5 | X2C | | I(A4)
| | | X2C | NC
| | | X2C | NC
| | | X2C | NC
| | | X2C | NC
| | f7-2 | X2C | | X1A(66); I(F7)
| | c28 | X2C | | X1A(78)
| | c29 | X2C | | X1A(79)
| | k5-2 | X2C | | X1B(92); I(K5)
| | k4-2 | X2C | | X1B(110); I(K4)
| | c32 | X2C | | X1B(154)
| | a2-3 | X2C | | I(A2)
| | b5-12 | X2C | | I(B5)
| | e9-3 | X2C | | I(E9)
| | d8-3 | X2C | | I(D8)
| | e7-2 | X2C | | X1A(68); I(E7)
| | f7-10 | X2C | | X1A(47); I(F7, H8)
| | f8-2 | X2C | | X1A(41); I(F8)
| | h7-2 | X2C | | X1A(63); I(H7)
| | | X2C | NC
| | | X2C | NC
| | | X2C | NC
| | | X2C | NC
| | b4-6 | X2C | | O(B4)

* NC: No Connect. * VCC: 5V. * GND: Ground. | * I: Input. * O: Output.

## Bảng kết nối của X160P-A

PIN NO. | PIN NAME | NET LABLE | ROW | I/O | NOTE
| | | X1A | VCC
| | | X1A | GND
| | t2-2 | X1A | | I(T2)
| | p2-1 | X1A | | I(P2)
| | | X1A | NC
| | p2-2 | X1A | | I(P2)
| | t2-1 | X1A | | I(T2)
| | | X1A | NC
| | | X1A | NC
| | | X1A | NC
| | y4-2 | X1A | | O(Y4)
| | t3-6 | X1A | | O(T3)
| | | X1A | NC
| | m5-6 | X1A | | O(M5)
| | p4-1 | X1A | | I(P4)
| | t6-2 | X1A | | I(W4, T6 )
| | t4-2 | X1A | | I(T4)
| | u2-2 | X1A | | O(U2)
| | | X1A | NC
| | p4-2 | X1A | | I(P4)
| | t4-1 | X1A | | I(T4)
| | m6-2 | X1A | | O(T2); I(M6)
| | u3-10 | X1A | | I(U3, U4)
| | m5-2 | X1A | | O(M5)
| | t3-10 | X1A | | O(T3)
| | m5-10 | X1A | | O(M5)
| | t3-2 | X1A | | O(T3)
| | m6-7 | X1A | | O(T1); I(M6)
| | m6-10 | X1A | | O(T1); I(M6)
| | m6-13 | X1A | | O(T1); I(M6)
| | w4-13 | X1A | | I(W4)
| | m3-12 | X1A | | O(M3)
| | m5-4 | X1A | | O(M5)
| | m2-9 | X1A | | I(M2, P1)
| | m7-2 | X1A | | O(M7)
| | t3-12 | X1A | | O(T3)
| | m5-12 | X1A | | O(M5)
| | m2-4 | X1A | | I(M2, P1)
| | t3-4 | X1A | | O(T3)
| | m2-12 | X1A | | I(M2)
| | u5-1 | X1A | | I(U5)
| | m3-4 | X1A | | O(M3)
| | m10-6 | X1A | | O(T9); I(M10, U10)
| | m7-4 | X1A | | O(M7)
| | m3-6 | X1A | | O(M3)
| | m2-2 | X1A | | O(T4, T6); I(M2, P1)
| | t5-1 | X1A | | I(T5)
| | m2-1 | X1A | | I(M2, P1)
| | m3-8 | X1A | | O(M3)
| | m9-1 | X1A | | O(P8); I(M9, P7)
| | m3-10 | X1A | | O(M3)
| | m3-2 | X1A | | O(M3)
| | u3-13 | X1A | | I(U3)
| | p7-6 | X1A | | I(P7, U10, W10, Y9, Z11, Z7)
| | | X1A | NC
| | w11-7 | X1A | | I(W11)
| | m3-5 | X1A | | O(P7); I(M3)
| | m7-8 | X1A | | O(M7)
| | p5-13 | X1A | | O(P5)
| | t7-8 | X1A | | O(T7, Y10); I(W5)
| | m7-10 | X1A | | O(M7)
| | p5-9 | X1A | | O(P5)
| | u8-1 | X1A | | I(U8)
| | p5-8 | X1A | | O(P5)
| | p10-3 | X1A | | I(P10, W10)
| | p8-1 | X1A | | I(P8)
| | m7-12 | X1A | | O(P7)
| | m6-1 | X1A | | I(M6)
| | m3-9 | X1A | | O(P7); I(M3)
| | t3-8 | X1A | | O(T3)
| | p10-7 | X1A | | I(P10)
| | m5-8 | X1A | | O(M5);
| | m7-6 | X1A | | O(M7);
| | u2-4 | X1A | | O(U2);
| | p5-14 | X1A | | O(P5);
| | t7-6 | X1A | | O(T7); I(W5)
| | | X1A | NC
| | t9-1 | X1A | | I(T9)
| | y10-1 | X1A | | I(Y11)
| | m9-8 | X1A | | O(M9, M11, W11, W1, P10, W2, Z3, Z1)
| | y4-4 | X1B | | O(Y4)
| | m11-3 | X1B | | O(T5, T8); I(M11, Y9)
| | m11-7 | X1B | | O(T10); I(M11)
| | u8-8 | X1B | | O(U8, Y11); I(W11, Z11)
| | p11-4 | X1B | | O(T11); I(P11)
| | m6-8 | X1B | | O(U5, M6); I(W11, Z7, W8)
| | u7-1 | X1B | | O(Y7); I(U7, Y4, Z8)
| | m9-7 | X1B | | I(M9)
| | m9-6 | X1B | | I(M9)
| | m5-1 | X1B | | O(Y7); I(M5, T7, U9)
| | t6-1 | X1B | | I(T6, U4)
| | t10-1 | X1B | | I(T10)
| | m9-5 | X1B | | I(M9)
| | t7-3 | X1B | | I(T7, U7, Y8, Z6)
| | t6-12 | X1B | | O(); I(T6)
| | m5-3 | X1B | | O(Y7); I(M5, T7, U9)
| | u7-2 | X1B | | O(Y7); I(U7, Y4, Z8)
| | t7-5 | X1B | | I(T7, U7, Y8, Z6)
| | m10-1 | X1B | | I(M10)
| | t6-13 | X1B | | I(T6)
| | u9-5 | X1B | | I(U9, Z10, Z9, Z8)
| | | X1B | NC
| | t6-11 | X1B | | O(T6)
| | u9-3 | X1B | | O(); I(U9, Z10, Z9, Z8)
| | | X1B | NC
| | m10-4 | X1B | | I(M10)
| | m5-9 | X1B | | O(W7); I(M5, P4, U7, Z8)
| | m5-11 | X1B | | O(W7); I(M5, P4, U7, Z8)
| | m10-3 | X1B | | I(M10)
| | t11-1 | X1B | | I(T11)
| | m9-3 | X1B | | O(P8); I(M9, P7)
| | m10-2 | X1B | | I(M10)
| | m5-13 | X1B | | O(W7); I(M5, T7, T4, U9)
| | m11-4 | X1B | | O(T5, T9); I(M11, Y9)
| | p10-5 | X1B | | O(Y10); I(P10, W10)
| | u8-14 | X1B | | O(U8, U9); I(W11, Z11)
| | m10-5 | X1B | | I(M10)
| | m5-5 | X1B | | O(W7); I(M5, P4, U7, Z8)
| | p10-1 | X1B | | O(T9); I(P10, U10)
| | m6-14 | X1B | | O(U5, M6); I(W11, W8 , Z7)
| | p2-5 | X1B | | I(P2, P4, T2, T4)
| | p2-3 | X1B | | I(P2, P4 , T2 ,T4)
| | | X1B | NC
| | | X1B | NC
| | m11-1 | X1B | | O(T5, T8); I(M11, Y9)
| | m9-2 | X1B | | O(P8); I(M9, P7)
| | m11-5 | X1B | | O(T10); I(M11)
| | p10-4 | X1B | | O(Y10); I(P10, W10)
| | m9-4 | X1B | | O(P8); I(M9, P7)
| | p10-6 | X1B | | O(Y10); I(P10, W10)
| | u8-3 | X1B | | O(U8, Y11); I(W11, Z11)
| | p10-2 | X1B | | O(T9); I(P10, U10)
| | m10-7 | X1B | | O(T9); I(M10, U10)
| | m6-3 | X1B | | O(U5, M6, W8); I(U5, Z7)
| | p11-2 | X1B | | O(T11); IP11()
| | | X1B | NC
| | | X1B | NC
| | | X1B | NC
| | | X1B | NC
| | | X1B | NC
| | | X1B | NC
| | | X1B | NC
| | m11-2 | X1B | | O(T5, T8); I(M11, Y9)
| | p11-1 | X1B | | O(T10); I(P11)
| | m11-6 | X1B | | O(T10); I(M11)
| | u8-5 | X1B | | O(U8, Y11); I(W11, Z11)
| | m6-5 | X1B | | O(M6, U5, W8); I(P11, Z7)
| | p11-5 | X1B | | O(T11); I(P11)
| | p11-3 | X1B | | O(T11); I(P11)
| | | X1B | NC
| | | X1B | NC
| | | X1B | NC
| | | X1B | NC
| | u3-9 | X1B | | I(U3, W4)
| | | X1B | NC
| | | X1B | NC
| | | X1B | NC
| | | X1B | NC
| | | X1B | GND
| | | X1B | VCC

* NC: No Connect. * VCC: 5V. * GND: Ground. | * I: Input. * O: Output.

Phân tích mạch khảo sát | 2

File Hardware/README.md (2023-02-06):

# Phần cứng của dự án:
# Bao gồm thiết kế mạch điện trên Altium và lập trình FPGA_SPT6.

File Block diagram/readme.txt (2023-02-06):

Mục này trình bày về các sơ đồ phục vụ thiết kế phần cứng và phần mềm trong dự án:
-Phần cứng:
    + Cấu trúc chương trình trên FPGA_SPT6(phần code lập trình)
    + Sơ đồ phân chia điện áp
    + Sơ đồ nguyên lý (Altium)
-Phần mềm:
    + Giao diện UI (lập trình QTcreator)
    + Cấu trúc chương trình

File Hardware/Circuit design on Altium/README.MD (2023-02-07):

# Thiết kế phần cứng (Mạch giao tiếp sử dụng phần mềm Altium)!!!
altium_2D
altium_3D
<br /><br /><br /><br /><br /><br />
<br /><br /><br />
<br /><br /><br /><br />
<br /><br />
altium_sche

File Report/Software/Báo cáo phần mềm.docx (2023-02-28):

Khung truyền thông bao gồm các thao tác:

+Nhấp “auto check connect”: Khi được nhấp, tại comboBox dưới dòng “Cổng hiện có” sẽ hiện số cổng COM cho phép kết nối truyền dữ liệu. Thông thường sẽ là COM 3.

+ Tại khung bên phải là chọn thông số cho giao thức UART bao gồm: cổng kết nối, số bit dữ liệu trong một khung truyền (Databit), số bít dừng (BitStop), tốc độ truyền b/s (Baud), cờ định hướng được chọn cùng stick (DTR), bit điều khiển (FlowControl), tín hiệu có bắt tay (Parity).

+ Sau khi chọn xong, nhấp vào button “CONNECT” cổng tương ứng sẽ xác định giao thức có các thông số truyền, nhận và hiển thị ở dòng “ket noi”.

+ Trong quá trình truyền có thể điều chỉnh độ trễ giao thức qua Spin Box dưới Combox hiện cổng có thể kết nối.

Khung Messenge: nơi thông báo các hoạt động của App bao gồm: truyền hay nhận, lưu file, kiểm tra, tiến trình. Ngoài ra cũng sẽ thông báo các vấn đề sau khi so sánh tín hiệu mẫu và thu được.

Được tạo ở phần kiểm tra App có chức năng truyền tín hiệu đi. Tại đây khi phát triển cũng là nơi thay thế và dùng để hiển thị các thao tác để truyền, nhận tín hiệu mẫu theo ý tưởng thực hiện đề tài.


Khung này bao gồm việc hiển thị tín hiệu, kiểm tra giữa hai tín hiệu “Mẫu” chuẩn và tín hiệu thu về từ bảng mạch (simulink) và hiện thị bảng mạch chỉ thị vị trí sai (nếu được) của bảng mạch. Trên trình hiển thị của simulink cho phép chức năng phóng to và thu nhỏ bằng chuột, điều này cho phép người dùng thuận tiện trong việc xem tín hiệu.

Code:

App được xây dựng từ QT một môi trường lập trình cung cấp các phương tiện, lớp thư viện của C++ và Python để xây dựng app cho Mobile hay PC.

Đề tài được lấy ý tưởng xây dựng ban đầu từ opensource của pulseview một Application dùng để hiển thị các tín hiệu digital và analog thu được thông qua kết nối USB. Nó giúp máy tính giống một máy hiện sóng thông thường. Nhờ tính năng này, ban đầu đã lấy nó làm cơ sở để phát triển ứng dụng nhưng do tính phức tạp được xây dựng từ Cmake không có hỗ trợ lớn từ qml. Vì thế nhóm đã định hướng sang các Example của Qt với UI có sẵn và các ví dụ về SerialPort để xây dựng app từ các thư viện hỗ trợ đồ họa của Qt lấy từ thư viện mẹ “QWidget” và kết nối “QserialPort”.

UI hỗ trợ rất lớn các công cụ xây dựng giao diện như LabView để xây dựng App. Với sự hỗ trợ mạnh mẽ từ các lớp với thư viện tương ứng cùng các thành phần hàm, kiểu xây dựng sẵn có thể đọc trên qt.doc. Giúp nhóm nhanh chóng tìm hiểu và liên kết các giao diện con và tạo chức năng tương ứng cho giao diện đó.

1.Kết nối.

Nhóm sử dụng lớp “QSerialPort” của Qt với các cung cấp kết nối với giao thức qua cổng COM trên máy tính, cho phép người dùng chọn cổng, baud truyền, số bít dữ liệu trong khung truyền, số bít dừng một khung, số bít điều khiển, cờ định hướng, tín hiệu bắt tay. Hiện QserialPort có thể hỗ trợ tốc độ truyền tương ứng của RS232 kiểu cũ cao nhất là 115200 bms. Tuy hạn chế nhưng cũng đảm bảo yêu cầu làm việc cho kiểm tra với phần cứng.

Phần code kết nối dùng cho làm việc với serialport được dựng trong lớp “serialportcnt.h” và “serialportcnt.cpp”. Bao gồm các hàm định nghĩa lại và tự định nghĩa như:

+Kiểu boolean begin(…), end(), send(…), recevei() có nhiệm vụ báo kết nối đã được set chưa, gửi tín hiệu kết thúc truyền nối tiếp, gửi – nhận tín hiệu.

+ Kiểu String setSerialInfo(), readAll() dùng để lên danh sách cổng đang kết nối và gửi thông tin của cổng được chọn để thiết lập kết nối truyền nối tiếp.

2.Hiện thị

Hiển thị nhóm dùng lớp “QMainWindow” được QT hỗ trợ cho window là đối tượng chính để kết nối. Ngoài ra có thể chuyển đổi để sử dụng môi trường tương ứng cho IOS, Linux sẽ được cấu hình tại file .pro (Hiện tại chỉ dừng ở window).

QMainWindow cung cấp một GUI mạnh cho window với khả năng làm như một trình giao diện kế thừa từ lớp mẹ QOBJECT là tiền thân cho mọi lớp trong QT. Với sự hỗ trợ mạnh mẽ về giao diện người dùng bằng UI. Người thiết kế có thể xây dựng nhanh chóng một giao diện có nhiều chức năng ví dụ như ComboBox, Button, Graphic, ProcessBar,…

Nhóm sử dụng thiết kế trên giao diện từ mainwindow.ui để thuận tiện quan sát và thao thác nhanh các chức năng của phần mềm.

a.Khung dành cho kết nối:

Bao gồm các ComboBox để chọn thuộc tính kết nối:

- ComboBox(danh sách cổng hiện có),
- comboBox_port(chọn cổng),
- comboBox_baud(chọn tốc độ truyền),
- comboBox_bitstop(chọn số bít dừng),
- comboBox_databit(chọn số bit dữ liệu trong một khung,
- comboBox_flowcontrol(chọn số bit điều khiển),
- comboBox_partity(tín hiệu bắt tay);

Ngoài ra còn có :

- radionButton(dùng để tự kiểm tra cổng kết nối sẽ hiển thị danh sách cho comboBox với thời gian lặp là 300 ms);
- spinBoxProcessingDelay(chọn độ trễ cho kết nối);
- checkBoxDTR( dùng để chọn có cờ định hướng) ;
- pushButton_uart: khi ấn sẽ là xác nhận thông tin cổng từ các comboxBox và mở cổng truyền. Lúc này nút sẽ hiện chữ “DISCONNECT”, khi ấn lần nữa sẽ đóng cổng, reset thuộc tính kết nối và hiện chữ “CONNECT”.


Cơ sở thời gian của toàn bộ app được xây dựng từ hàm CreateBase():


b. Đồ thị và bảng mạch mô phỏng chức năng.

QT có hỗ trợ một wigdet được xây dựng tối ưu hóa cho vẽ biểu đồ và đồ thị một cách trực quan và đẹp nhất bằng thư viện “qcustomplot”. Thư viện được nhóm dùng để xây dựng đồ thị tín hiệu trên widgetsimulink nằm trong khung của tabWidget trên UI. Vì gọi ‘ui->widgetsimulink->…’ không ảnh hưởng gì đến tabWidget. Tại đây, tabWidget chỉ có nhiệm vụ chuyển đổi widget trong nó giữa hai phần hiển thị là simulink( ứng với tín hiệu) và schematic( ứng với bảng mạch được mô phỏng).

Trên simulink, vì tín hiệu bảng nhớ là các tín hiệu nhị phân nên việc hiển thị nhóm hiển thị dạng xung vuông có tín hiệu mức 1 và 0.

Trên schmatic, nhóm dùng các label để hiện thị phần tử IC trên bảng mạch với lớp Qpixmap cho phép hiển thị ảnh và hàm với label.move(x,y) để hiện thị vị trí của nó trên schmatic. Khi so sánh tín hiệu báo sai thì sẽ thay label là một ảnh IC có màu đỏ để báo nó sai.

c.Thông báo.

Tiện cho việc kiểm tra quá trình thực hiện chức năng, nhóm xây dựng một textBrowser giúp thông báo như một ‘applicate out’ để báo cáo quá trình như: kết nối, lưu file tín hiệu, báo cáo lỗi sai,…

Hàm addMes(QString text, bool agrT) sẽ viết tiếp vào textBrowser ứng với hiện thị là khung dưới Messenger chuỗi ‘text’ khi biểu thức boolean agrT là đúng còn sai thì không báo.


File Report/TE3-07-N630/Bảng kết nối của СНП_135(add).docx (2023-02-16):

## Bảng kết nối của СНП-135.

PIN NO. | PIN NAME | NET LABLE | ROW | I/O | NOTE
| | e4-14 | X2A | O | O(F8, E7); O(T9); I(M10, U10); I(E4, F5)
| | d1-14 | X2A | O | O(F8, E7); O(T9); I(M10, U10); I(D1, F3)
| | e7-8 | X2A | O | O(E7, F8); O(T9); I(P10, U10); I(F4, H4)
| | e7-14 | X2A | O | O(E7, F8); O(T9); I(P10, U10); I(F2, K3)
| | b3-14 | X2A | O | O(U5,M6, W8); I(U5, Z7) I(B3, E3)
| | b2-14 | X2A | O | O(M6, U5, W8); I(P11, Z7); I(B2, E2)
| | e4-3 | X2A | O | O(H8); O(P8); I(M9, P7); I(E4, F5)
| | d1-3 | X2A | O | O(H8); O(P8); I(M9,P7); I(D1, F3)
| | f4-3 | X2A | O | O(H8); O(P8); I(M9, P7); I(F4, H4)
| | f2-3 | X2A | O | O(H8); O(P8); I(M9, P7); I(F2, K3)
| | b3-3 | X2A | O | O(T5, T8); I(M11, Y9); I(B3, E3)
| | b2-3 | X2A | O | O(T5, T8); I(M11, Y9); I(B2, E2)
| | e4-13 | X2A | O | O(H7); I(P10, W10); I(E4, F5)
| | d1-13 | X2A | O | O(H7); O(Y10); I(P10, W10); I(D1, F3)
| | f4-13 | X2A | O | O(H7); O(Y10); I(P10, W10); I(F4, H4)
| | f2-13 | X2A | O | O(H7); O(Y10); I(P10, W10); I(F2, K3)
| | b3-13 | X2A | O | O(U8, Y11); I(W11, Z11); I(B3, E3)
| | b2-13 | X2A | O | O(U8, Y11); I(W11, Z11); I(B2, E2)
| | e4-2 | X2A | O | O(K5); I(M9); I(E4, F5)
| | d1-2 | X2A | O | O(K5); I(M9); I(D1, F3)
| | f4-2 | X2A | O | O(K5); I(M9); I(F4, H4)
| | f2-2 | X2A | O | O(K5); I(M10); I(F2, K3)
| | b3-2 | X2A | O | O(T10); I(M11); I(B3, E3)
| | b2-2 | X2A | O | O(T10); I(M11); I(B2, E2)
| | e4-1 | X2A | O | O(K4); I(M10); I(E4, F5)
| | d1-1 | X2A | O | O(K4); I(M10); I(D1, F3)
| | f4-1 | X2A | O | O(K4); I(M10); I(F4, H4)
| | f2-1 | X2A | O | O(K4); I(M10); I(F2, K3)
| | b3-1 | X2A | O | O(T11); I(P11); I(B3, E3)
| | b2-1 | X2A | O | O(T11); I(P11); I(B2, E2)
| | e8-1 | X2A | I | I(M2, P1); I(E8)
| | e8-12 | X2A | I | I(M2); I(E8)
| | b6-3 | X2A | I | I(B6)
| | f9-8 | X2A | I | I(H10, K7, K9, F9)
| | f9-9 | X2A | I | I(F9, H10, K7, K9)
| | f9-10 | X2A | I | I(F9, H10, K7, K9)
| | a37 | X2A | I | I(T6, U4)
| | a38 | X2A | I | I(T7, U7, Y8, Z6)
| | a39 | X2A | I | I(T7, U7, Y8, Z6)
| | a40 | X2A | I | I(U9, Z10, Z9, Z8)
| | a41 | X2A | I | I(U9, Z10, Z9, Z8)
| | a42 | X2A | I | I(P2, P4, T2, T4)
| | a43 | X2A | I | I(P2, P4 , T2 ,T4)
| | | X2A | NC
| | | X2A | NC
| | | X2B | GND
| | d5-14 | X2B | O | O(U5, M6); I(W11, Z7, W8); I(D5, E5)
| | b3 | X2B | I | I(W4, T6)
| | | X2B | VCC
| | d2-14 | X2B | O | O(U5, M6); I(W11, W8 , Z7); I(D4, D2)
| | b6 | X2B | I | I(U3, U4)
| | d5-3 | X2B | O | O(T5, T8); I(M11, Y9); I(D5, E5)
| | b8 | X2B | I | I(W4)
| | d2-3 | X2B | O | O(T5, T9); I(M11, Y9); I(D2, D4)
| | | X2B | VCC
| | b11 | X2B | I | I(U3)
| | b12 | X2B | I | I(P7, U10, W10, Y9, Z11, Z7)
| | | X2B | GND
| | d5-13 | X2B | O | O(U8, Y11); I(W11, Z11); I(D5, E5)
| | b6-1 | X2B | O | O(B6)
| | d2-13 | X2B | O | O(U8, U9);I(W11, Z11); I(D2, D4)
| | b6-4 | X2B | O | O(B6)
| | | X2B | VCC
| | d5-2 | X2B | O | O(T10); I(M11); I(D5, E5)
| | b6-10 | X2B | O | O(B6)
| | | X2B | GND
| | d2-2 | X2B | O | O(T10); I(P11); I(D2, D4)
| | b6-13 | X2B | O | O(B6)
| | | X2B | NC
| | | X2B | GND
| | d5-1 | X2B | O | O(T11); I(P11); I(D5, E5)
| | d2-1 | X2B | O | O(T11); I(P11); I(D2, D4)
| | | X2B | VCC
| | | X2B | NC
| | | X2B | NC
| | b31 | X2B | O | O(M9, M11, W11, W1, P10, W2, Z3, Z1)
| | e8-9 | X2B | I | I(M2, P1); I(E8)
| | | X2B | GND
| | e8-4 | X2B | I | I(M2, P1); I(E8)
| | | X2B | NC
| | | X2B | VCC
| | a4-3 | X2B | O | O(A4); I(A4)
| | b38 | X2B | I | I(T6)
| | b39 | X2B | I | I(T6)
| | | X2B | NC
| | | X2B | NC
| | | X2B | VCC
| | f7-5 | X2B | O | O(F7); I(P10)
| | f7-3 | X2B | O | O(F7); I(W11)
| | | X2B | GND
| | e7-1 | X2C | O | O(P5); I(E7)
| | e7-6 | X2C | O | O(P5); I(E7)
| | e7-9 | X2C | O | O(P5); I(E7)
| | e7-12 | X2C | O | O(P5); I(E7)
| | c5 | X2C | O | O(T2); I(M6)
| | c6 | X2C | O | O(T1); I(M6)
| | c7 | X2C | O | O(T1); I(M6))
| | c8 | X2C | O | O(T1); I(M6)
| | b2-8 | X2C | I | I(D1, D2, D5, B2, B3, E4, F2, F4)
| | b2-9 | X2C | I | I(D1, D2, D5, B2, B3, E4, F2, F4)
| | b2-10 | X2C | I | I(D1, D2, D5, B2, B3, E4, F2, F4)
| | d4-8 | X2C | I | I(D4, E2, E3, E5, F3, F5, H4, K3)
| | d4-9 | X2C | I | I(D4, E2, E3, E5, F3, F5, H4, K3)
| | d4-10 | X2C | I | I(D4, E2, E3, E5, F3, F5, H4, K3)
| | | X2C | NC
| | b4-8 | X2C | O | O(B4)
| | a10-1 | X2C | I | I(A10)
| | a10-4 | X2C | I | I(A10)
| | b10-13 | X2C | I | I(B10)
| | | X2C | NC
| | a4-4 | X2C | I | I(A4)
| | a4-5 | X2C | I | I(A4)
| | | X2C | NC
| | | X2C | NC
| | | X2C | NC
| | | X2C | NC
| | f7-2 | X2C | I | I(P8); I(F7)
| | c28 | X2C | I | I(P8)
| | c29 | X2C | I | I(Y11)
| | k5-2 | X2C | I | I(T10); I(K5)
| | k4-2 | X2C | I | I(T11); I(K4)
| | c32 | X2C | I | I(U3, W4)
| | a2-3 | X2C | I | I(A2)
| | b5-12 | X2C | I | I(B5)
| | e9-3 | X2C | I | I(E9)
| | d8-3 | X2C | I | I(D8)
| | e7-2 | X2C | I | I(M6); I(E7)
| | f7-10 | X2C | I | I(T5); I(F7, H8)
| | f8-2 | X2C | I | I(U5); I(F8)
| | h7-2 | X2C | I | I(U8); I(H7)
| | | X2C | NC
| | | X2C | NC
| | | X2C | NC
| | | X2C | NC
| | b4-6 | X2C | O | O(B4)

* NC: No Connect. * VCC: 5V. * GND: Ground. | * I: Input. * O: Output.

ROW | IN | OUT | I/O | VCC | GND | NC
X2A | 13 | 30 | 43 | 0 | 0 | 2
X2B | 9 | 18 | 27 | 6 | 6 | 6
X2C | 25 | 10 | 35 | 0 | 0 | 10
TOTAL | 47 | 58 | 105 | 6 | 6 | 18
| 105

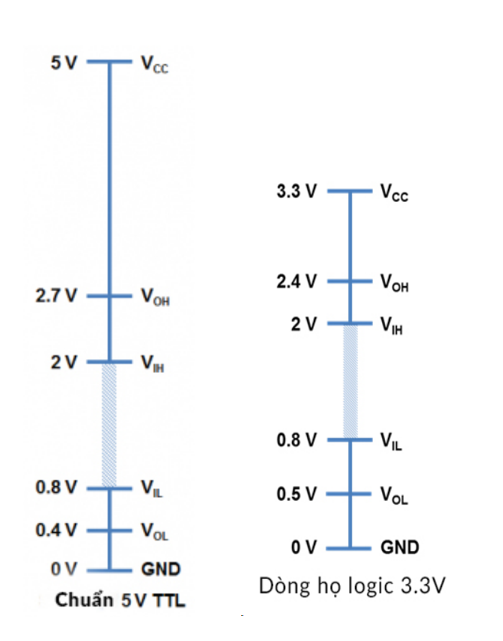
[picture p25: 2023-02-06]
Hardware/Circuit design on Altium/DataSheet/logic/logic.png

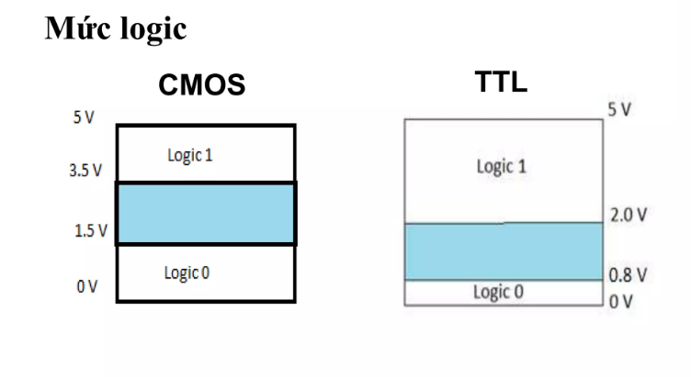
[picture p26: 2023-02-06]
Hardware/Circuit design on Altium/DataSheet/logic/mức logic.png

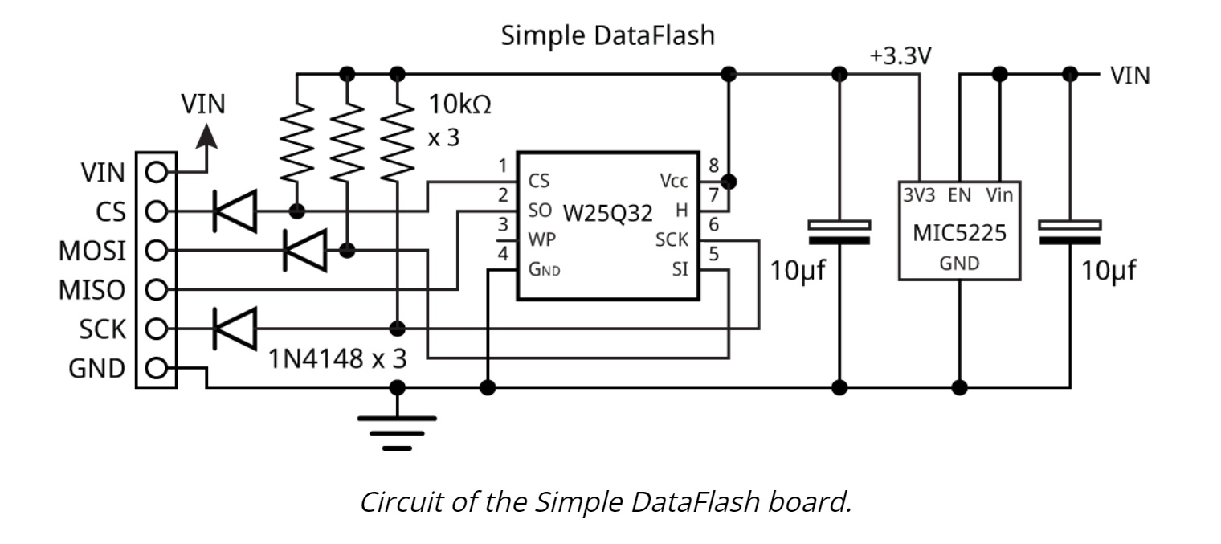
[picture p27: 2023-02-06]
Hardware/Circuit design on Altium/DataSheet/sche/Flash_Rom_W25Q.png

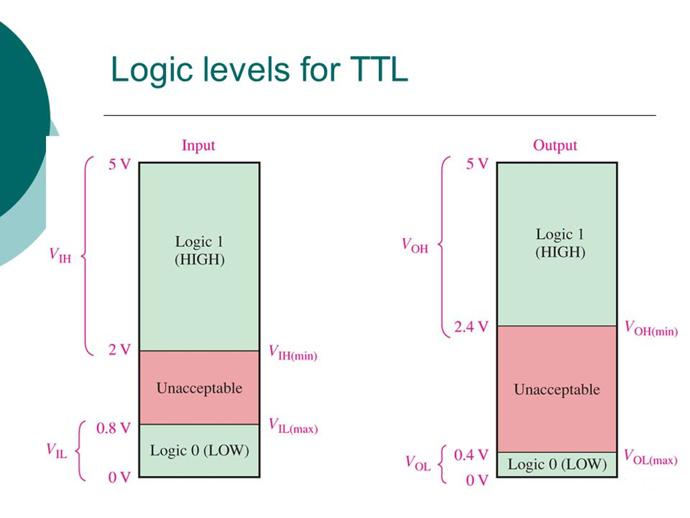
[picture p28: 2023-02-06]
Hardware/Circuit design on Altium/DataSheet/logic/TTL Logic.png

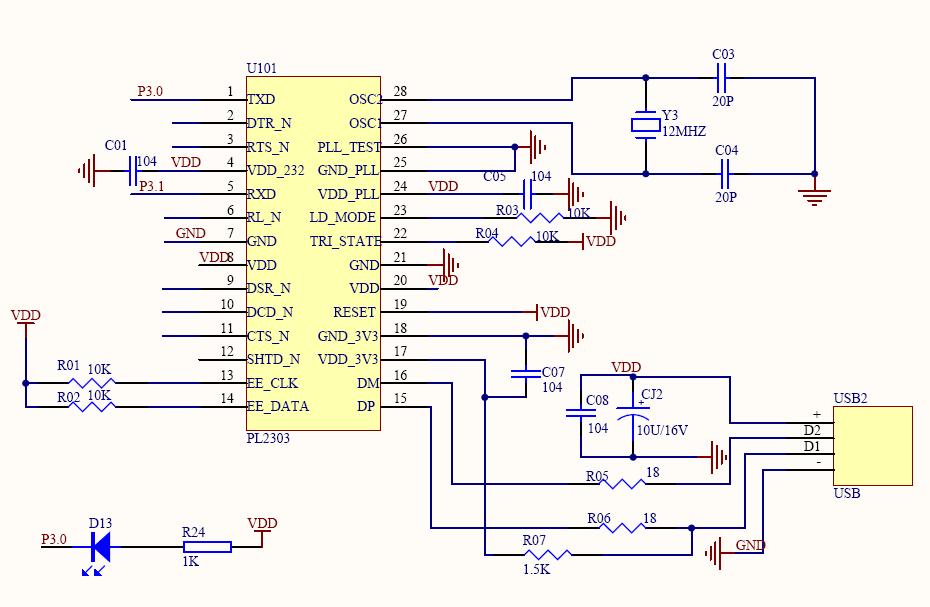
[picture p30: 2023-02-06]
Hardware/Circuit design on Altium/DataSheet/sche/PL2303_schematic.jpg

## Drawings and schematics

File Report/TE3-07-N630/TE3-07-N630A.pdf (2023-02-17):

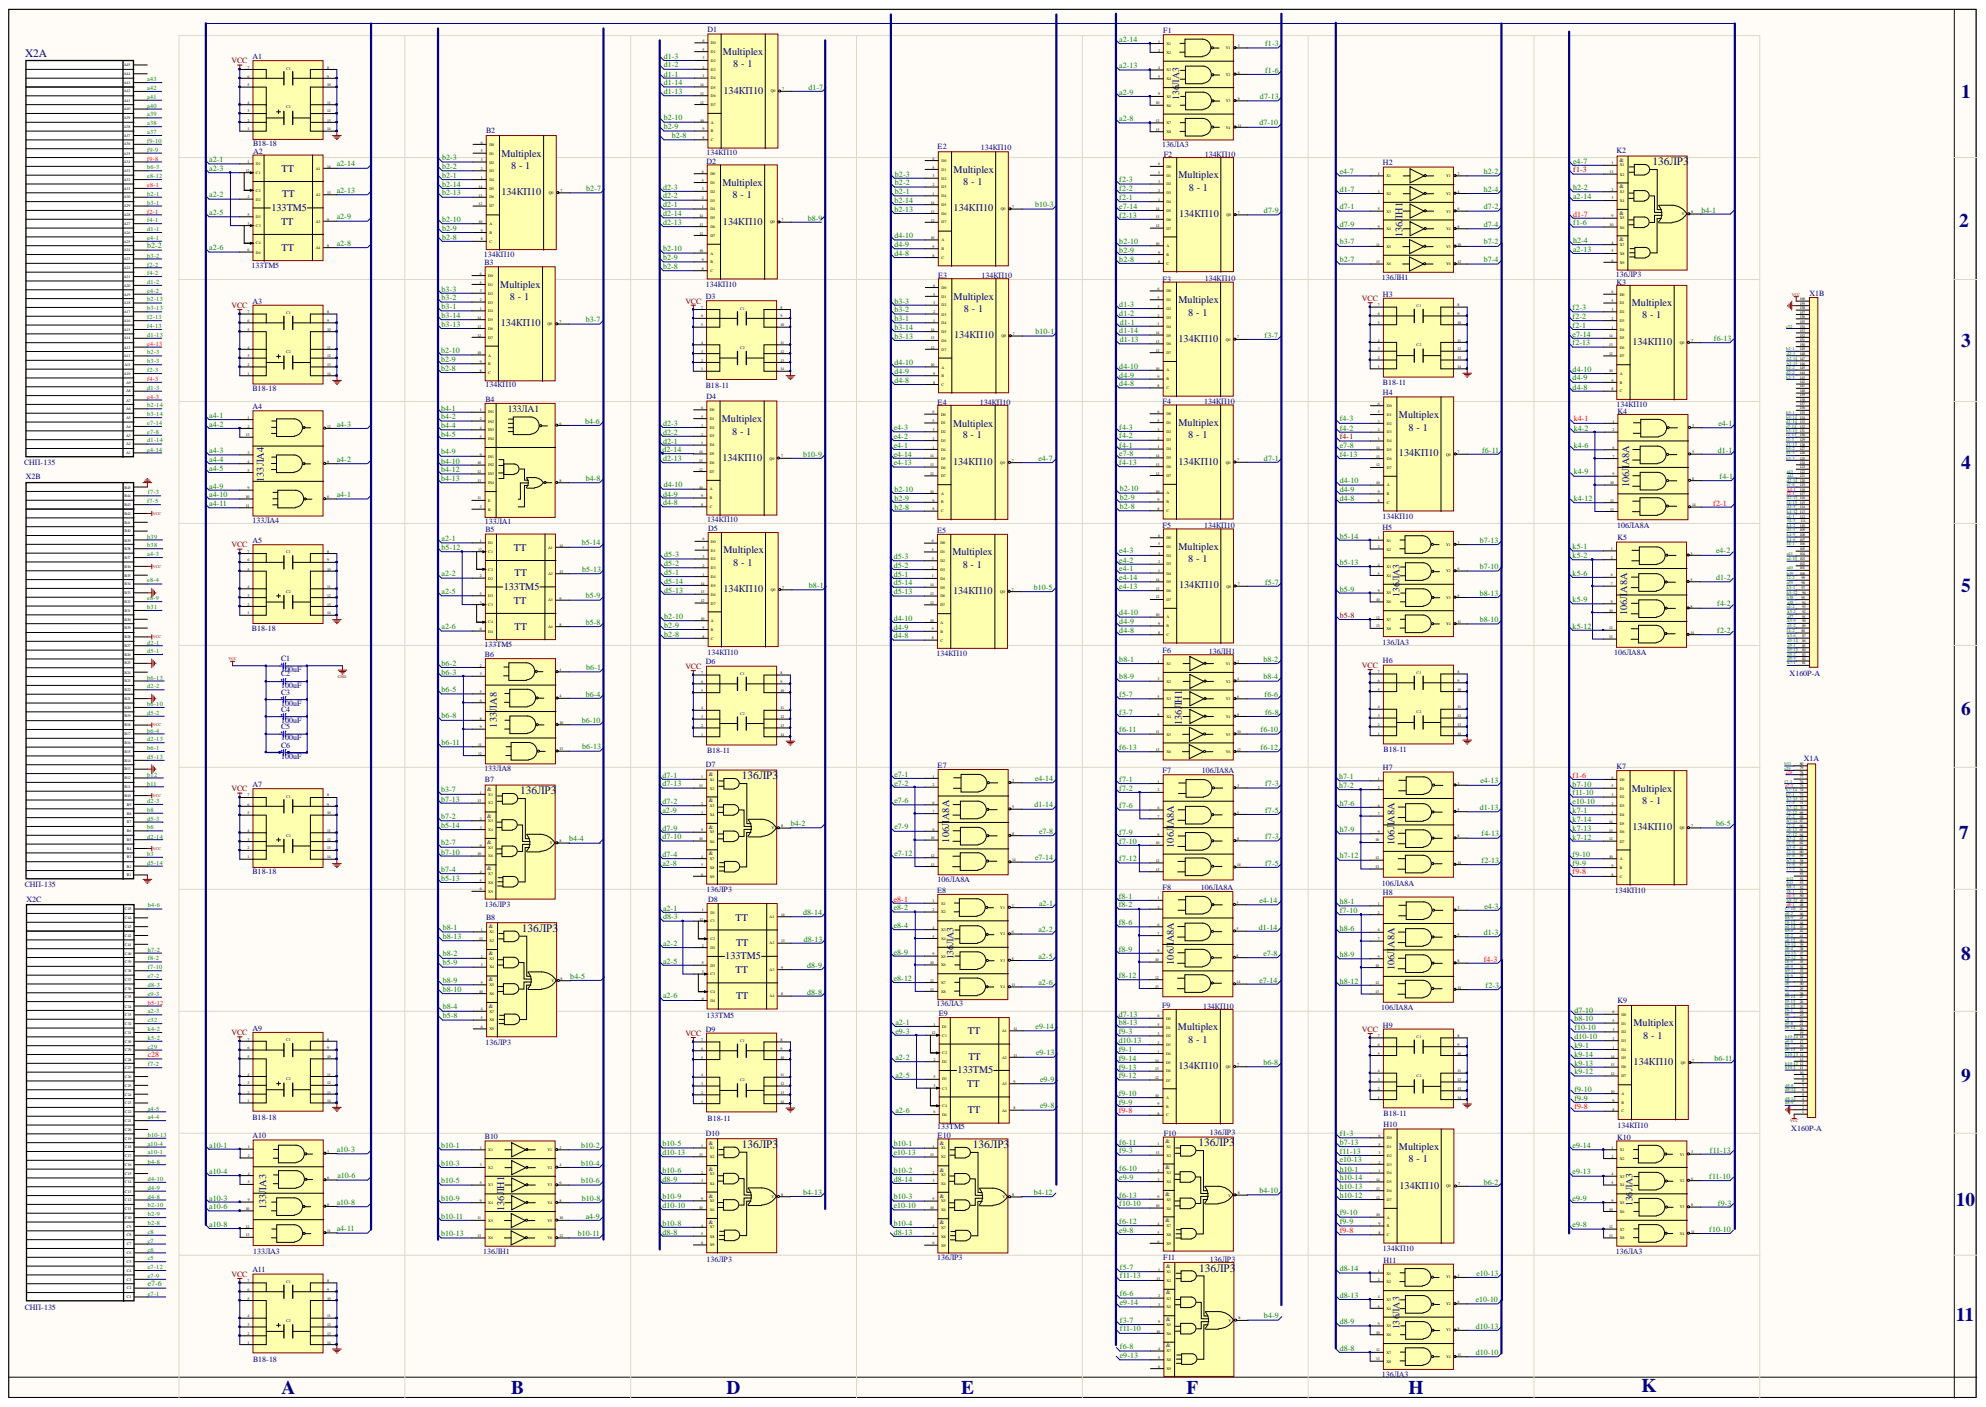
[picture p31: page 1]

# Board Stack Report

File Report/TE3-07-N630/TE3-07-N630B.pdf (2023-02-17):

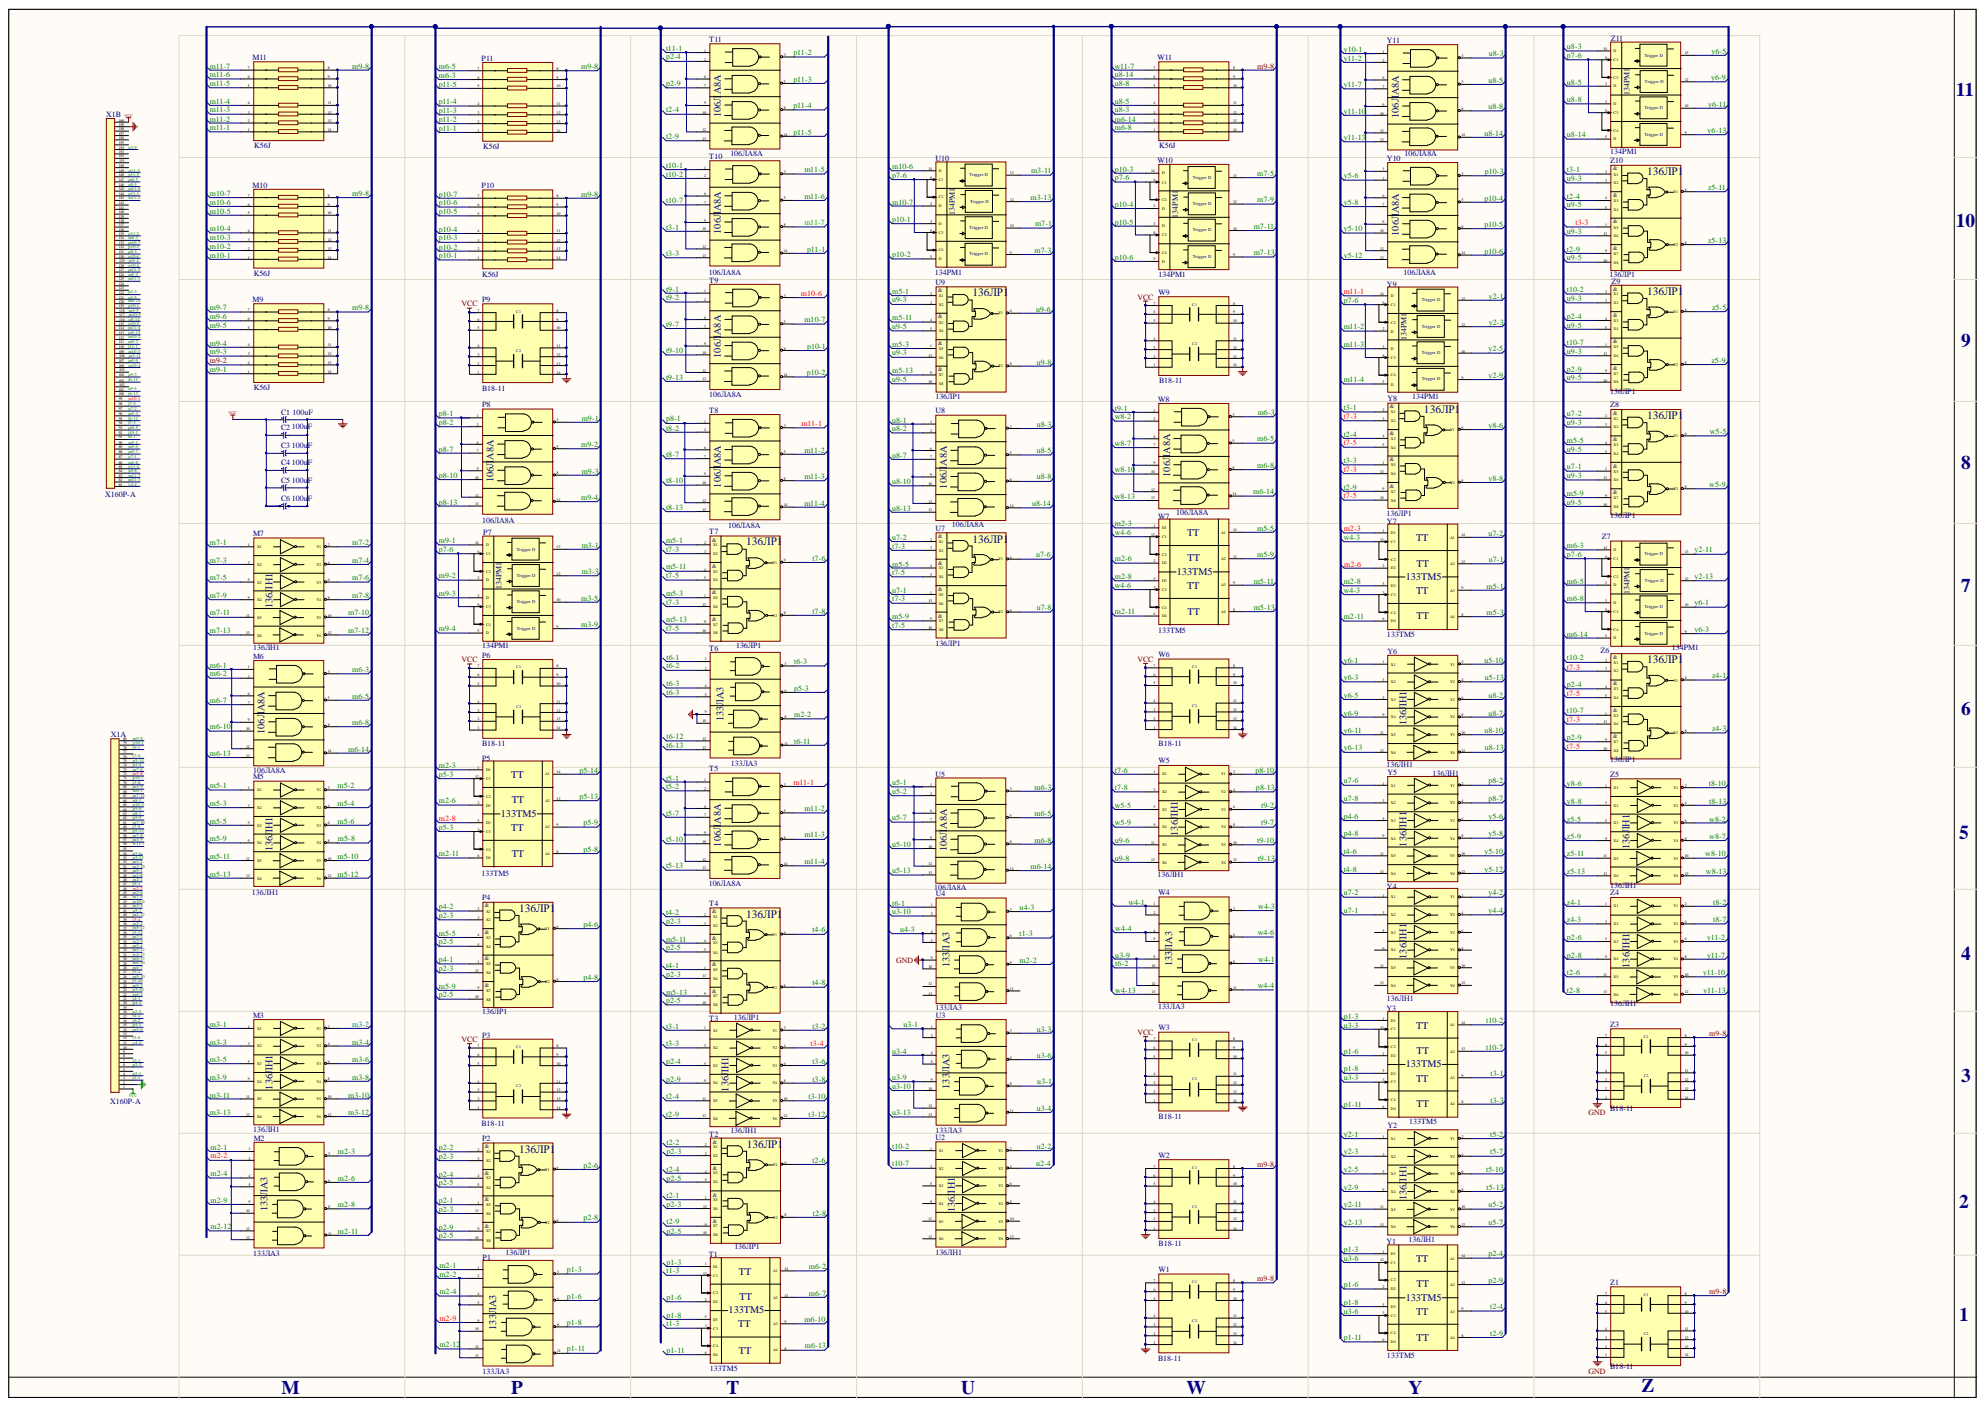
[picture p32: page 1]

D 14 C1 6 | Trigger D

VCC C1 100uF | P8 p8-1 3 m9-1 | T8 | U8 | t9-1 | 1 | 3 m6-3 | t3-1 | & X1 2 | y8-6 | Z8

# Board Stack Report

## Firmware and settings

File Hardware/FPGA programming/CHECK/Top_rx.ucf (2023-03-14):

net "ckht" loc = p55;
net "btn_rst" loc = p59;
net "empty" loc = p105;
net "xdgm" loc = p112;
net "rx" loc = p93;

net "data_out[0]" loc = p92;
net "data_out[1]" loc = p88;
net "data_out[2]" loc = p87;
net "data_out[3]" loc = p85;
net "data_out[4]" loc = p84;
net "data_out[5]" loc = p83;
net "data_out[6]" loc = p82;
net "data_out[7]" loc = p81;

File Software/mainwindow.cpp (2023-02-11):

#include "mainwindow.h"
#include "ui_mainwindow.h"

MainWindow::MainWindow(QWidget *parent) : QMainWindow(parent), ui(new Ui::MainWindow)
{
    ui->setupUi(this);
    setWindowTitle("Text System");
    CreateBase();
    //connect(ui->lineEditsend->text(),SIGNAL(returnPressed()), this, SLOT(on_comboBoxSendReturnPressedSlot()));}
}

MainWindow::~MainWindow()
{
    delete ui;
}

void MainWindow::addMess(QString text, bool agrT)
{
    if(false) // Sau nay co the gan vao button de bat/tat chuc nang nay
    {
        if(!agrT)
        {
              ui->textBrowser->append(text);
        }
    }
    else
    {
        ui->textBrowser->append(text);
    }
}

//Ham tao co so thoi gian cho APP
void MainWindow::CreateBase()
{
    this->serialDeviceTimer = new QTimer(this);
    this->radioButtonTimer = new QTimer(this);
    this->serialStingProcessTimer = new QTimer(this);
    this->upStringProcessingTimer = new QTimer(this);

    connect(serialStingProcessTimer,SIGNAL(timeout()), this, SLOT(on_pushButton_clicked));
    connect(radioButtonTimer, &QTimer::timeout,this, [=](){ui->radioButton->setCheckable(false);});


}

//Ham bao cho ui->TextBrower khi truyen data qua COM
void MainWindow::serialsend(QString messenger)
{

    if (!serialcnt.send(messenger))
        this->addMess("App >>\t Unable to send! Serial port closed !", true);
    else
    {
        sendMessSerial();
        saveFile("TextSample.txt");
    }
}

void MainWindow::sendMessSerial()
{
    QString datasends = ui->lineEditsend->text();
    addMess("\n >>" +datasends,true);
}

void MainWindow::saveFile(QString const fileSave)
{
    QFile file(fileSave);

    if(file.open(QIODevice::WriteOnly | QIODevice::Text))
    {
        if(serialcnt.recevei()){
            QString datasave = serialcnt.readAll();
           // upStringProcessingTimer->start(1000);
            QTextStream stream(&file);
            stream << datasave;
            addMess("Nhan duoc: "+ datasave + " || hoan thien",true);
        }
        addMess("\n Saved at file: " + fileSave , true);

    }

}

//QString portnamez,qint32 baudz, QString databitz,
//QString parityz, QString stopbitz,QString flowctrlz,bool dtrOn
void MainWindow::on_pushButton_uart_clicked()
{
   QString portnamez = QSerialPortInfo::availablePorts().at(ui->comboBox->currentIndex()).portName();
   uint baudz = ui->comboBox_baud->currentText().toInt();
   QString databitz = ui->comboBox_databit ->currentText();
   QString parityz = ui->comboBox_partiy->currentText();
   QString bitstopz = ui->comboBox_bitstop->currentText();
   QString flowctrlz = ui->comboBox_flowcontrol->currentText();

//show thong tin ket noi taij label_messUart

   ui->label_mesUart->setText(portnamez+ ",Baud: "+ui->comboBox_baud->currentText()+ ",dataBit: "+
                              databitz+ ", Bitstop:"+ bitstopz+ ", flowctrl:"+ flowctrlz);
   if(serialcnt.begin(portnamez,baudz,databitz,parityz,bitstopz,flowctrlz,ui->checkBoxDTR->isChecked()))
   {
       serialStingProcessTimer->start(1000); //cho simulink

       connect(serialStingProcessTimer, SIGNAL(timeout()), this, SLOT(on_processSerial()));
       ui->pushButton_uart->setText("Disconnect");
       //addMess(); phan trong ham dung cho label_mesUart

   }
   else
   {
       serialStingProcessTimer ->stop();
       disconnect(serialStingProcessTimer, SIGNAL(timeout()), this, SLOT(on_processSerial()));

       if(serialcnt.end())
       {
            ui->pushButton_uart->setText("connect");
       }
       else
       {
           ui->pushButton_uart->setCheckable(true);
       }
       if(!ui->pushButton_uart->isCheckable())
       {
           // dong file
           qDebug() << "Dong chuc nang file";
       }
   }

}

//Ham check cac cong COM dang co voi nut radiobutton duoc nhap lan dau
void MainWindow::on_radioButton_toggled(bool checked) //chua dung bool cheched
{
    QList<QSerialPortInfo> device = serialcnt.getAvailiblePorts();
    QList<QString> portName;
    static QList<QString> portNameOld;

    ui->radioButton->animateClick(500);

    foreach (auto item, device)
        portName.append(item.portName());
    if (device.count() >= 1)
    {
        ui->comboBox->clear();

        for (auto i = 0; i < device.count(); ++i)
        {
            ui->comboBox->addItem("(" + device.at(i).portName() + ")" );
            ui->radioButton->setDown(true);
        }
    }
    else if ((device.count() < 1) && !ui->comboBox->itemText(0).startsWith("No COM devices"))
    {
        ui->comboBox->clear();
        ui->comboBox->addItem("No serial devices detected :(");
        ui->comboBox->setCurrentIndex(ui->comboBox->count() - 1);
        ui->radioButton->setDown(false);
    }

}

//Button cho phep gui data qua COM dang ket noi
void MainWindow::on_pushButton_gui_clicked()
{
    QString datasend = ui->lineEditsend->text();
    serialsend(datasend);
}

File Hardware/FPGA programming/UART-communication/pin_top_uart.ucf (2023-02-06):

#    ckht  : in std_logic; -- 50Mhz
#    rst   : in std_logic;
#
#    uart_rx : in std_logic;      -- baudspeed 19200 bps
#    uart_tx : out std_logic;
#
#    fifo_rx_ena_rd  : in std_logic; -- yeu cau doc du lieu tu fifo
#    fifo_rx_data_out: out std_logic_vector(7 downto 0); -- du lieu ra song song
#    fifo_rx_empty   : out std_logic;  -- fifo bao trang thai trong
#
#    fifo_tx_ena_wr  : in std_logic; -- yeu cau ghi du lieu vao fifo
#    fifo_tx_data_in : in std_logic_vector(7 downto 0);  -- du lieu vao song song
#    fifo_tx_full    : out std_logic -- fifo bao trang thai day

net "ckht" loc = p55;
net "rst" loc = p59;

net "uart_rx" loc = p93;
net "uart_tx" loc = p94;
net "fifo_rx_ena_rd" loc = p67;

#led
net "fifo_rx_data_out[0]" loc = p92;
net "fifo_rx_data_out[1]" loc = p88;
net "fifo_rx_data_out[2]" loc = p87;
net "fifo_rx_data_out[3]" loc = p85;
net "fifo_rx_data_out[4]" loc = p84;
net "fifo_rx_data_out[5]" loc = p83;
net "fifo_rx_data_out[6]" loc = p82;
net "fifo_rx_data_out[7]" loc = p81;

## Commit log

2023-02-05 Thêm các thư mục
2023-02-06 Thêm sơ đồ
2023-02-06 thêm mô tả một số sơ đồ
2023-02-06 thêm mô tả
2023-02-06 Thêm mục giao tiếp UART
    Truyền thông giữa PC với FPGA
2023-02-06 Mạch giao tiếp version1
    V1
    [M_G_T.PrjPcb, PCB_Mach_giao_tiep.PcbDoc, SCH_Mach_giao_tiep.SchDoc]
2023-02-06 Mạch giao tiêp Version2
    V2
    [M_G_T.PcbDoc, M_G_T.PrjPcb, M_G_T.SchDoc]
2023-02-06 Update Library
    [PKY_LIB.PcbLib, PKY_LIB.SchLib, ThuVien.PcbLib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]
2023-02-06 Create Chữ viết tắt.docx
2023-02-06 Create GIAO TIẾP UART.docx
2023-02-06 Create THIẾT KẾ MẠCH GIAO TIẾP.docx
2023-02-08 Create New Tài liệu văn bản.txt
2023-02-11 phần mềm nằm trong mục này
2023-02-16 Create Bảng kết nối của СНП_135(add).docx
2023-02-16 Update THIẾT KẾ MẠCH GIAO TIẾP.docx
2023-02-17 Update Sơ đồ các khối mô phỏng.drawio
2023-02-17 Update GIAO TIẾP UART.docx
2023-02-17 Create Tổng quan về thiết bị chuẩn đoán.docx
2023-02-26 Update Sơ đồ các khối phần cứng.drawio
2023-03-14 update sche
    [M_G_T.PcbDoc, M_G_T.PrjPcb, M_G_T.SchDoc]
